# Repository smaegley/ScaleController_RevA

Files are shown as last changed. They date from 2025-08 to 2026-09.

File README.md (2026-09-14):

Scale Controller Rev-A

A custom ESP32-based scale controller PCB derived from the KLP-5e ESP32 Sensor Board. This design integrates an HX711 24-bit ADC and supports 4× half-bridge load cells, with output to a 1.3” SSD1306 OLED display over I²C. The board is designed to run ESPHome, making it easy to integrate into Home Assistant or other IoT ecosystems.

⸻

✨ Features
	•	ESP32-C3-WROOM-02-H4 module (RISC-V, Wi-Fi + BLE)
	•	USB-C connector for power and flashing (via on-board CP2102N USB-UART bridge, with USBLC6 ESD protection)
	•	Onboard LM1117 LDO regulator (5V → 3.3V)
	•	HX711 24-bit ADC for load cell integration
	•	4× JST-PH-3 connectors for half-bridge load cells
	•	1× JST-PH-4 header for I²C OLED (SSD1306 128×64, 1.3”)
	•	Tare via the on-board BOOT button (SW1, GPIO9) — no extra hardware needed
	•	J6 expansion header (5-pin): 3V3, GPIO8, GPIO18, GPIO19, GND

Verified pin map (from the KiCad netlist):

| Function | ESP32-C3 GPIO | Notes |
|---|---|---|
| HX711 DOUT | GPIO6 | |
| HX711 PD_SCK | GPIO5 | |
| I²C SDA (OLED)  | GPIO4 | |
| I²C SCL (OLED)  | GPIO3 | |
| Tare button | GPIO9 | reuses BOOT button SW1 (on board) |

Rev-A has no dedicated user I/O beyond the BOOT-button tare; status is shown on
the OLED and in Home Assistant. A physical status LED (GPIO19) is deferred to Rev-B.

⸻

🛠️ Getting Started

Hardware Bring-Up Checklist
	1.	Power via USB-C → check +3.3V rail is stable.
	2.	I²C scan → OLED should respond at 0x3C.
	3.	HX711 baseline → confirm stable raw counts with no load.
	4.	Add load cells one by one → verify diagonal pairs add/subtract as expected.
	5.	Tare with empty platform.
	6.	Calibrate using a known mass (e.g. 1000 g). Compute calibration factor.

ESPHome Config

The full, ready-to-build configuration lives in firmware/scale-controller.yaml
(targets the ESP32-C3 with the verified pin map above). To use it:

	1.	Install ESPHome (pip install esphome or the Home Assistant add-on).
	2.	cp firmware/secrets.yaml.example firmware/secrets.yaml and fill in your Wi-Fi/API/OTA values.
	3.	esphome run firmware/scale-controller.yaml (first flash over USB-C, then OTA).

Key pins (see firmware/scale-controller.yaml for the complete config):

i2c:
  sda: GPIO4
  scl: GPIO3

sensor:
  - platform: hx711
    id: hx711_raw
    dout_pin: GPIO6
    clk_pin: GPIO5
    gain: 128

⸻

📂 Repo Structure
	•	KiCad project/ScaleController_RevA.kicad_pro — main KiCad project
	•	KiCad project/*.kicad_sch — schematics (root + ESP32-C3, HX711 load-cell summing, OLED header; user_interface is nested under the ESP32-C3 sheet)
	•	KiCad project/ScaleController_RevA.kicad_pcb — PCB layout (footprints placed; routing not yet started)
	•	firmware/scale-controller.yaml — ESPHome configuration
	•	fabrication/ — Gerbers, BOM, pick-and-place (generated; gitignored)
	•	docs/ — bring-up notes, calibration steps

⸻

⚖️ License & Attribution

This project is licensed under the CERN Open Hardware Licence Version 2 – Strongly Reciprocal (CERN-OHL-S v2).

Derived from futureshocked/KLP-5e-ESP32-sensor-board.
Copyright © 2025 Steve Maegley
Copyright © 2022–2023 futureshocked

You are free to use, modify, manufacture, and distribute this design, provided that you release your modifications under the same license.

⸻

🚀 Next Steps
	•	Schematic is complete for Rev-A (tare = BOOT button GPIO9; status LED deferred to Rev-B)
	•	Route the PCB (keep HX711 analog away from the antenna + regulator)
	•	Run DRC and fix violations
	•	Generate fabrication files (Gerbers, BOM, pick-and-place)
	•	Build Rev-A prototype and validate
	•	Document calibration workflow with photos

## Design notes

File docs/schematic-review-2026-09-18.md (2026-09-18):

# Schematic review — Scale Controller Rev-A, 18 September 2026

Method: every pin of every part checked from the exported netlist (`kicad-cli sch export
netlist`, commit 83b06ee) against the part datasheets — ESP32-C3-WROOM-02 v1.4,
CP2102N rev 1.5, HX711, LM1117, USBLC6-2SC6. Not a visual review; wiring only.

## Verdict

The board will power up, boot from flash and run. Two real design errors were found, both
in the programming path, plus a handful of robustness items. None require holding the
PCB order if the Rev-A workarounds below are acceptable.

## Findings

### F1 — Auto-program circuit is driven from a CTS input; the CP2102N QFN20 has no DTR  (design error)

`U4` is the **QFN20** CP2102N. Its pin 15 is **CTS (input)** and pin 16 is RTS; the QFN20
package has no DTR/DSR/DCD/RI (datasheet §5.3, Table 5.3). The classic ESP auto-reset
circuit (Q2/Q3, R33/R34) needs DTR *and* RTS as host-driven outputs. Here the net named
"DTS" is wired to CTS, which the host cannot drive.

Consequences, in order of importance:

1. **A host that asserts RTS holds the ESP32 in reset.** CTS floats high (CP2102N inputs
   default to weak pull-up, §4.3.1), so Q2's base is high; when the host asserts RTS the pin
   goes low, Q2 conducts and pulls EN low. Generic terminals (`screen`, `minicom`, pyserial
   defaults on Linux) assert RTS on open, so the board appears dead while the monitor is
   open. `esptool` and `esphome logs` de-assert RTS after opening, so those work.
2. **Automatic entry into download mode cannot work.** Q3 needs its emitter (DTS) driven
   low; nothing ever does. Flashing requires holding **BOOT (SW1)** while the tool resets
   the chip (esptool's RTS toggle still resets it, so hold BOOT, start esptool, release).

Rev-A: **do not populate Q2, Q3, R33, R34.** Program with BOOT + EN; use ESPHome OTA after
the first flash. This also removes consequence 1.
Rev-B: drop the CP2102N entirely and use the C3's native USB-Serial/JTAG on GPIO18/19
(already on J6), keeping U5 for ESD — or move to the QFN24/QFN28 CP2102N which has DTR.
Either way, rename the net.

### F2 — GPIO8 floats; it must be high to enter download boot  (design error)

ESP32-C3 Table 4: GPIO8 default **floating** (no internal pull). Table 6: Joint Download
Boot requires GPIO2 = 1, **GPIO8 = 1**, GPIO9 = 0. On this board GPIO8 goes only to J6
pin 2. With it floating, download mode is undefined — flashing may fail or be intermittent.

Rev-A: 10 kΩ between **J6 pin 1 (3.3 V) and J6 pin 2 (GPIO8)** — a resistor across two
adjacent header pins, no board rework. Rev-B: add the pull-up on the board.

### F3 — GPIO2 floats; datasheet recommends a pull-up  (robustness)

Table 6 note 2: "GPIO2 does not determine the boot mode, but it is recommended to pull this
pin up due to glitches." Module pin 16 is unconnected. Most boards run fine without it.
Rev-A: accept, or solder 10 kΩ from pad 16 to 3.3 V if boot proves flaky. Rev-B: add it.

### F4 — No I2C pull-ups on SDA/SCL  (robustness)

`/SDA` and `/SCL` contain only U3 and J9. The bus relies on the OLED module's on-board
pull-ups (most SSD1306 modules carry 4.7–10 kΩ; confirm on the Hosyond board) or the
C3's ~45 kΩ internal pull-ups. Rev-B: 4.7 kΩ pair on the board so J9 works with any module.

### F5 — BOOT (GPIO9) has no external pull-up  (robustness)

Relies on the C3's internal weak pull-up (~45 kΩ, Table 4 says default 1). With C21
(0.1 µF) that is a 4.5 ms rise, versus the 10 ms EN delay from R32/C22 — OK, but 10 kΩ to
3.3 V is the Espressif reference and makes the latch timing comfortable. Rev-B.

### F6 — HX711 input filter corner is very high  (optional)

R15/R16 100 Ω with C12/C13 4.7 nF gives f_c ≈ 340 kHz — nearly no filtering of the bridge
signal. Harmless (many HX711 boards have none). Rev-B option: 1 kΩ + 10 nF C0G ≈ 16 kHz.
Keep the parts matched between channels.

### F7 — HX711 AGND pin is on GND, everything else analogue is on AGND  (note)

U6 pin 5 → GND directly; C12–C17, VFB, INB±, RATE → AGND, tied to GND at NT1. Electrically
identical; only the physical tie point matters. Layout was done with this in mind (17 Sept
note). No action.

### F8 — TX/RX LEDs need one-time CP2102N configuration  (note)

D5/D6 hang off GPIO.2/GPIO.3. Datasheet §4.3.1: GPIO pins default to GPIO input
(open-drain, weak pull-up), so the LEDs stay off until TXT/RXT alternate functions are
enabled with Simplicity Studio's Xpress Configurator over USB. Not a fault.

## Verified correct

- **USB-C**: VBUS A4/A9/B4/B9 → /VBUS; D+/D− both rows paired; CC1/CC2 each 5.1 kΩ to GND
  (Rd, sink); SBU NC; shield and GND to GND.
- **ESD**: USBLC6-2SC6 pins 1/6 and 3/4 are the same internal line; connector side on
  6/4, chip side on 1/3; VBUS on 5, GND on 2.
- **Power path**: VBUS → F1 (1.1 A PPTC) → FB1 → +5V → U2 VIN. LM1117 SOT-223 pinout
  (1 GND, 2/4 VOUT, 3 VIN) correct. 10 µF tantalum in, 3 × 10 µF tantalum + ceramics out —
  meets the ESR requirement. Dissipation ≈ 0.25 W average, 0.6 W at Wi-Fi TX peaks: fine
  with the pour.
- **CP2102N**: regulator-bypassed mode (VDD = VREGIN = 3.3 V, datasheet Fig. 2.3);
  RSTb 1 kΩ pull-up (Fig. 2.1 recommends exactly 1 kΩ); VBUS sense divider 22.1 k / 47.5 k
  matches Fig. 2.6; 1 µF on the VBUS pin. UART correctly crossed: U4 TXD → U3 RXD, U4 RXD
  ← U3 TXD.
- **ESP32-C3 module**: pin map matches the WROOM-02 table; EN has 10 kΩ + 1 µF + button;
  3V3 and all 21 GND pins connected. IO3/IO4 (I2C), IO5/IO6 (HX711), IO18/19/8 to J6.
- **HX711 external-supply configuration**: VSUP = AVDD = DVDD = 3.3 V, VFB → AGND, BASE NC
  (regulator disabled, per datasheet application circuit); VBG 0.1 µF; RATE low = 10 SPS;
  XI grounded = internal oscillator; channel B inputs tied to AGND. Bridge excitation E+/E−
  is the same 3.3 V rail as AVDD, so the measurement is ratiometric.
- **Load-cell wiring**: J3/J7 feed S+, J5/J8 feed S−, and the S− pair has E+/E− swapped on
  the board, so all four half-bridge cells plug in identically (white/red/black) and every
  corner produces a same-sign output. This is the standard 4-cell parallel Wheatstone.
  For the most even corner response, mount the S+ pair (LC1/LC3 = J3/J7) diagonally.
- **Firmware pins** (`firmware/scale-controller.yaml`) match the netlist: DOUT GPIO6,
  PD_SCK GPIO5, SDA GPIO4, SCL GPIO3, tare on GPIO9.
- **OLED J9**: GND, 3V3, SCL, SDA — matches the module's pin order.
- No unintended shorts: every named net has the expected members; only intended pins are
  unconnected (IO0/1/2/7/10, SBU1/2, CP2102N GPIO/suspend/wakeup, HX711 BASE/XO).

## Recommended actions

| when | action |
|---|---|
| Rev-A order | Order as is. Mark **Q2, Q3, R33, R34 DNP** on the assembly BOM (or don't fit them). |
| Rev-A bring-up | 10 kΩ across J6 pins 1–2 (GPIO8 pull-up). Flash with BOOT held; OTA afterwards. |
| Rev-B | Native USB (GPIO18/19) instead of CP2102N; pull-ups on GPIO2, GPIO8, GPIO9; 4.7 kΩ I2C pull-ups; optional 1 kΩ/10 nF HX711 filter; status LED on a free GPIO. |

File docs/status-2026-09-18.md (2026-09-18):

# Scale Controller Rev-A — Status, 18 September 2026

Supersedes `status-2026-09-17.md`. Pre-order checklist complete, schematic review done and
its findings **designed out** (see below); fab package regenerated from the reworked board.
DRC 0 errors / 0 unconnected, ERC 0 symbol mismatches, schematic↔board parity clean.

## Design rework after the schematic review (evening)

`docs/schematic-review-2026-09-18.md` found that the QFN20 CP2102N has no DTR, so the
DTR/RTS auto-program circuit could never work, and that GPIO8 floated (needed high for
download boot). Rather than work around it, the USB path was redesigned:

- **CP2102N and its 13 support parts removed** (U4, R11–R13, C9–C11, D6, R18, Q2, Q3,
  R33, R34). USB D+/D− now run from the ESD diode U5 to the module's native
  USB-Serial/JTAG pins (IO19 = D+, IO18 = D−). esptool/ESPHome reset and enter download
  mode over USB by themselves; no buttons needed for flashing. UART0 is broken out on J6.
- **Pull-ups added**: R3 10 k GPIO8, R4 10 k GPIO2, R5 10 k GPIO9/BOOT, R6/R7 4.7 k SDA/SCL.
- **Status LED**: D5 (green) + R14 330 R kept and re-homed to **GPIO7** (active-low), placed
  between the module and the HX711 with a STATUS silk label. ESPHome `status_led` drives it.
- **J6 re-pinned**: 1 = 3.3 V, 2 = GPIO10, 3 = U0TXD (GPIO21), 4 = U0RXD (GPIO20), 5 = GND.
- Board: the five long back-side bus lines between the module and J6 were kept and
  re-terminated (USB pair on the top two, UART on the next two, GPIO10 on the fifth,
  extended to pad 10). GPIO8 and STATUS_LED run down the free channel between the PD_SCK
  and SDA diagonals. I2C/IO2 pull-ups sit in the right-edge strip. 44 parts, 23 BOM lines.
- Firmware: `logger: hardware_uart: USB_SERIAL_JTAG`, `status_led` on GPIO7, pin map updated.

## Done today

- **Design rules**: deleted the global `annular_width` ignore from `.kicad_dru` (nothing
  needs it since the DFM pass). Restored `min_copper_edge_clearance` to **0.3 mm** — the DFM
  commit set it, but the GUI zone-refill save that followed wrote the old project file back
  over it (0.2). Board meets 0.3 either way.
- **Stackup**: PCBWay standard 4-layer 1.6 mm — 7628 prepreg 0.19 mm ×2, core 1.03 mm,
  1 oz on all four layers. Gerber job file now carries it.
- **Symbol libraries**: `LM1117MPX-3.3_NOPB`, `ESP32-C3-WROOM-02-H4` and `MTMM-103-03-T-S-150`
  rewritten in KiCad 9 format from the schematic copies. The MTMM copy has pins 1/2/3 (JST PH
  pads); the old library still had 01/02/03, so "update from library" would have unwired the
  sockets. SnapEDA `Description_1` junk fields removed everywhere.
- **BOM fixes**: J3/J5/J7/J8 → JST **B3B-PH-K-S** (symbol name unchanged); J1 → HRO
  **TYPE-C-31-M-12**; C9 value 4.7u → 10u to match its KEMET T491A 10 µF part number
  (LM1117 output cap); capacitor values normalised to `0.1u / 1u / 10u` so identical 0805
  parts group (30 → 27 BOM lines). Legacy KLP-5e `BOM.ods` deleted.
- **DRC exclusions**: the 4 silk-over-edge warnings (J1 face, U3 antenna notch) excluded in
  the GUI. Remaining warning: U3 footprint differs from library — intentional.
- **Fab package** in `fabrication/RevA-2026-09-18/` (git-ignored, regenerate as below):
  schematic PDF (6 pages), `-BOM.csv` (all fields), `-BOM-PCBWay.csv` (coalesced
  manufacturer/MPN), Gerbers + Excellon drill (Protel ext., separate PTH/NPTH, drill maps),
  `-gerbers.zip`, `-pos-top.csv` (43 parts), `-pos-bottom.csv` (J9 only).
- **Order notes**: `docs/pcbway-order-notes.md`.
- **Package as sent**: built from commit 271f942 (final refill); `ScaleController_RevA-gerbers.zip`
  14 files, sha256 starts `dd51ac8b2ae7093b`. Regenerating from that commit reproduces it.

## Regenerating the outputs

```
cd "KiCad project"
kicad-cli sch export pdf -o ../fabrication/RevA-<date>/ScaleController_RevA-schematic.pdf ScaleController_RevA.kicad_sch
kicad-cli sch export bom -o ../fabrication/RevA-<date>/ScaleController_RevA-BOM.csv \
  --fields 'Reference,${QUANTITY},Value,Footprint,MF,Manufacturer_Name,MANUFACTURER,MP,Manufacturer_Part_Number,Mouser Part Number,Description,Datasheet,${DNP}' \
  --group-by 'Value,Footprint,MP,Manufacturer_Part_Number' --ref-range-delimiter '' ScaleController_RevA.kicad_sch
kicad-cli pcb export gerbers -o ../fabrication/RevA-<date>/gerbers/ \
  -l F.Cu,In1.Cu,In2.Cu,B.Cu,F.Paste,B.Paste,F.SilkS,B.SilkS,F.Mask,B.Mask,Edge.Cuts --subtract-soldermask ScaleController_RevA.kicad_pcb
kicad-cli pcb export drill -o ../fabrication/RevA-<date>/gerbers/ --excellon-separate-th --excellon-units mm --generate-map ScaleController_RevA.kicad_pcb
kicad-cli pcb export pos -o ../fabrication/RevA-<date>/ScaleController_RevA-pos-top.csv --side front --format csv --units mm --exclude-dnp ScaleController_RevA.kicad_pcb
kicad-cli pcb export pos -o ../fabrication/RevA-<date>/ScaleController_RevA-pos-bottom.csv --side back --format csv --units mm --exclude-dnp ScaleController_RevA.kicad_pcb
```

## PCBWay order (placed 18 Sept, under review)

| item | product no. | qty | quoted |
|---|---|---|---|
| PCB, 4-layer 90 × 52.9 mm 1.6 mm, green/white, HASL-LF, 6/6 mil, 0.3 mm | W1153444AS5P3 | 5 | $32.66, 4–5 days |
| Assembly, turnkey, top side, 22 unique / 38 SMD / 5 THT, J9 not fitted | T-5P4W1153444A | 5 | $29.00 + components (quoted after review) |

Files uploaded: gerbers.zip, BOM-PCBWay.csv, pos-top.csv, assembly-top.pdf. Sales rep: Chloe.

## Next

1. Upload `ScaleController_RevA-gerbers.zip` to PCBWay with the notes in
   `docs/pcbway-order-notes.md`; pick surface finish (no fine-pitch QFN any more, so
   lead-free HASL is fine; ENIG still nicer for the 0.5 mm-pitch module pads).
2. If quoting assembly: `-BOM-PCBWay.csv` + `-pos-top.csv`. 11 of 23 lines are generic
   (0805 R/C, header/socket) — fill in exact MPNs/LCSC numbers if that matters. C12/C13/C16
   dielectrics and the HX711 source are specified in the BOM; check the quote honours them.
3. Enclosure: the J9 display mount is prototype-only. Decide between a different mount
   and integrating the display on the board for Rev-B (see 17 Sept note for standoffs,
   hole positions, and USB/antenna overhangs).
4. Bring-up per `TODO.md` once boards arrive.

## Working notes

- Headless copper edits: never use a generic "dangling end" sweep over live areas — a track
  ending on the *middle* of another track (T-junction) looks dangling to a naive endpoint
  test. Delete by explicit coordinates and let DRC's `track_dangling`/`via_dangling` list
  guide the next pass.
- Headless edits to `.kicad_pro` are lost if any KiCad editor is open, even without a
  visible lock — the GUI writes the project file back on save/close. Edit it only when
  the whole project is closed, then check `git diff` after Steve's next GUI save.
- `kicad-cli` on VM 201 has no global symbol/footprint libraries, so ERC shows 85
  `lib_symbol_issues` and DRC shows `lib_footprint_issues` when run outside the project
  dir. Both are environment noise; run from `KiCad project/` for a faithful DRC.

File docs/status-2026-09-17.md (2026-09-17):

# Scale Controller Rev-A — Status, 17 September 2026

Supersedes `status-2026-09-15.md`. Board fully routed, DRC 0 errors / 0 unrouted,
5 benign warnings, everything pushed (`origin/main` = c55ba90).

## Changes since 15 Sept

- **Load-cell sockets** → JST PH B3B-PH-K (2.0 mm, friction lock). One connector pair
  is inverted on the board (J3/J7 vs J5/J8) so all four half-bridge cells plug in
  identically: pin 1 white, pin 2 red (centre tap), pin 3 black. Legend on silk.
  Rows at 5.7 mm pitch; NT2/NT3 moved above the column.
- **USB-C** → HRO TYPE-C-31-M-12 (SMD signal pins, four PTH shell legs), replacing the
  Bel hybrid whose staggered PTH row failed PCBWay's hole-spacing and ring limits.
  Added R1/R2 5.1 kΩ CC pull-downs (board now powers from C-to-C cables and chargers).
  Rendered with the GCT USB4105 3D model as stand-in (KiCad ships no HRO model).
- **Display header J9** moved to the **back side**, pin order **GND, 3V3, SCL, SDA**
  to match the Hosyond 0.96" I2C module. The module plugs in from below and lies
  flat under the board, clear of the load-cell sockets. DISP1 is a pad-less
  placeholder footprint + model for fit checks only (nominal 27 × 27.5 mm).
- **DFM for PCBWay**: all vias 0.6/0.3 mm (0.15 mm ring; one 0.55/0.3 at U4 pad 8),
  ESP32 module ground-grid pads 0.6 mm, copper-to-edge rule 0.3 mm, net-class vias
  0.6/0.3, U4 pin 12 grounded into the centre pad (via in pad).
- Silkscreen labels; standard-library footprints refreshed; E+/E− naming tidied.

## Before ordering (in order)

1. `.kicad_dru`: replace the global `annular_width` ignore with one scoped to U3's
   ground grid.
2. Board stackup → PCBWay standard 4-layer 1.6 mm (7628 prepreg ≈0.19 mm after
   lamination, 1.03 mm core, 1 oz all layers).
3. Outputs: schematic PDF, BOM from schematic (delete the KLP-5e `BOM.ods`),
   Gerbers + drill (Protel extensions), pick-and-place (top side; J9 and the JST
   sockets are THT).
4. PCBWay order notes: one 0.55 mm via (U4-VBUS, ring 0.125 mm); J1 footprint
   peg-to-shell-leg hole spacing 0.35 mm is the manufacturer's geometry; J9 is a
   bottom-side THT part (hand-solder if not assembling THT).

## Enclosure notes

- Standoffs ≥ 14 mm under the board for the display module.
- Buttons and USB face up; display faces down through J9 → decide board orientation.
- USB-C face protrudes ~1.2 mm past the board edge; ESP32 antenna overhangs the top edge.
- Four M3 mounting holes: (116, 76.5) (116.5, 119.5) (197, 120.5) (169, 84) mm in
  board coordinates; board 89.9 × 52.8 mm with the antenna notch top right.

## Working notes

- Headless edits (`scratchpad/pcbtool.py` + per-task design scripts) are verified with
  `kicad-cli pcb drc` on a fill-stripped copy, then written only while the PCB editor
  is closed; Steve refills in the GUI afterwards.
- KiCad symbol pin numbers must match footprint pad names ("1" vs "01"), or Update PCB
  silently drops the pad nets. Check netlist *membership* after any connector swap.

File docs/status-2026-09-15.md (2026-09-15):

# Scale Controller Rev-A — Status, 15 September 2026

## Where things stand

**The board is fully routed and passes DRC.** 0 unrouted connections, 0 errors,
4 warnings (all intentional or cosmetic, see below). Everything is committed and
pushed; `origin/main` is current.

| Item | State |
|---|---|
| Schematic | Complete for Rev-A. ERC 0 errors. |
| Placement | Done. 4× M3 mounting holes added (H1–H4). |
| Routing | 141/141 connections. 350 track segments, 66 vias, 4-layer (F.Cu / In1 GND plane / In2 3.3V plane / B.Cu). |
| DRC | 0 errors. Warnings: J1 + U3 differ from library copies (deliberate), 2× module silk outline over the antenna edge. |
| Footprints | Standard parts refreshed from KiCad 9 libraries; J1 and U3 kept on their modified copies. |

## What was fixed along the way (14–15 Sept)

Bugs found in the inherited design, all corrected in the schematic and reflected on the board:

- **Three separate 3.3V nets** (`3.3V`, `+3.3V`, `+3V3`) left the HX711 and the OLED
  unpowered. Unified onto one net.
- **HX711 input filters were wired in series** (S± → 100R → 4.7 nF → INA±), which
  blocks the DC bridge signal. Rewired as shunt caps to AGND.
- Stale KLP-5e leftovers removed: test points TP2/TP4, 104 silkscreen items,
  eight top-layer copper islands, duplicate ground zones, In2 power islands.
- Net classes: two classes had zero-annular-ring vias; `+5V` was in no class.
- Board had no mounting holes.

Layout decisions worth knowing:

- Load-cell connectors were re-ordered so the two S+ cells are adjacent
  (J3, J7) and the two S− cells adjacent (J5, J8). Wire the cells accordingly.
- HX711 cap/resistor column re-ordered pin by pin; NT2/NT3 net ties moved beside
  the connectors. AGND meets GND only at NT1.
- A five-lane bottom-layer bus runs along the top edge (between the antenna
  keepout and mounting hole H4) carrying the UART pair and GPIO8/18/19.
- USB D± use short bottom-layer hops around the connector's mirrored pin rows.
- J1 (USB-C) has a custom DRC rule allowing 0.127 mm between its own pads and a
  solid connection to the ground plane; J1 and U3 allow bridged mask apertures.

## Before ordering boards

1. **Silkscreen labels** — all board-level silk was purged. Needed: connector
   names and load-cell assignment (S+ → J3/J7, S− → J5/J8), BOOT/EN buttons,
   J6 pin names (3V3, GPIO8, GPIO18, GPIO19, GND), OLED header pins, board
   name and revision.
2. **Fab capability check** — J1's through-hole row has 0.35 mm hole-to-hole
   spacing; JLCPCB lists 0.5 mm. This footprint was built in the KLP-5e
   prototypes, but confirm with the chosen fab. Also confirm the 4-layer
   stackup (file has 0.1 mm prepregs; fabs will substitute their standard).
3. **Design rules** — `ScaleController_RevA.kicad_dru` has a global rule that
   silences the annular-ring check; narrow it to the ESP32 module's ground grid.
4. **Outputs** — schematic PDF, BOM with LCSC numbers, Gerbers + drill,
   pick-and-place. Then a quote.

## Working notes

- Mac ↔ VM: the repo is edited from the Mac over `smb://10.0.1.121/projects`.
  `.git` is hidden from the share (Samba veto) and KiCad's git integration is
  disabled on the Mac; both were needed after a git index got wiped on 14 Sept.
- Workflow that worked: Steve routes in the GUI in small chunks, Claude verifies
  each save with `kicad-cli` DRC. Dense sections (analog, the long digital runs)
  were designed headlessly on a scratch copy, DRC-verified, and written to the
  board with the PCB editor closed.
- KiCad 9.0.9 on both sides. Do not move to KiCad 10 during Rev-A.

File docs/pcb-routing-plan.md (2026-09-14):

# ScaleController Rev-A — PCB Routing & Layout Plan

Status as of 2026-07-05: **55 footprints placed, 0 tracks routed.** Board is
~90 × 53 mm, 4-layer. This document is the routing strategy — the actual work
happens in the KiCad PCB editor. It is grounded in the current placement and
the verified netlist (68 nets), not generic advice.

The single most important idea for this board: **it is a mixed-signal design.**
The HX711 measures the load cell bridge at the **microvolt** level, sitting a
few cm from a 2.4 GHz Wi-Fi radio and a switching USB bridge. Most of the plan
below exists to keep that tiny analog signal clean.

---

## 1. Layer stackup (4-layer)

Current layers: `F.Cu` (signal), `In1.Cu` (power), `In2.Cu` (power), `B.Cu` (signal).

**Recommended assignment:**

| Layer | Use |
|---|---|
| F.Cu | Primary signal routing + component side |
| In1.Cu  | **Solid, unbroken GND plane** (layer type stays "power plane"; KiCad has no separate ground type) |
| In2.Cu  | Power pours: +3.3V (main), with +5V/VBUS islands as needed |
| B.Cu | Secondary signal routing + GND fill |

Why: a continuous ground plane directly under the signal layers gives every
trace a clean, low-impedance return path — this is the biggest single lever for
both analog noise and Wi-Fi/USB EMI. **Do not split or slot In1.Cu**, especially
not under the HX711, the ESP32, or the USB pair. (See §5 for how analog ground
is handled *without* cutting the plane.)

Set the board thickness/stackup so the F.Cu↔In1.Cu spacing is small (thin
prepreg) — it tightens return-path coupling and helps controlled impedance for
the USB pair.

---

## 2. Placement zones (already mostly good)

From current coordinates (mm), the board self-organizes into two zones:

```
     LEFT / CENTER  (power + digital + USB)        RIGHT (analog + RF)
   ┌───────────────────────────────────┬──────────────────────────────┐
   │ J6 expansion (far left)            │              U3 ESP32-C3 (top)│  <- antenna to top edge
   │ U2 LM1117 LDO   D4/5/6 LEDs        │                               │
   │ U4 CP2102N   U5 USBLC6             │   J3 ┐                        │
   │ F1 fuse  FB1 ferrite               │   J5 ├ load cells   U6 HX711  │
   │ SW1 BOOT  SW2 EN                   │   J7 │             C12-C17 dcpl│
   │ J1 USB-C (bottom edge)             │   J8 ┘                        │
   └───────────────────────────────────┴──────────────────────────────┘
```

**Keep this separation.** The mixed-signal boundary runs roughly vertically
through the middle. Route so that digital/USB/switching currents stay left, and
analog stays right.

Placement tweaks to check before routing:
- **U6 (HX711) decoupling caps** C12–C17 are in a column at x≈181.8 — good, keep
  each cap's ground via right at the pad.
- **Load-cell connectors J3/J5/J7/J8** feed `E+/E-` and `S_PLUS_GRP/S_MINUS_GRP`
  into the summing network → HX711 INA±. Keep them close and grouped (they are).
- Confirm **U3's PCB antenna overhangs the top board edge** (U3 is at y≈82.8,
  top edge y≈72.2). See §6.

---

## 3. Net classes (already defined — good)

The project already has sensible classes. Confirm these before routing:

| Class | Track  | Clearance | Notes |
|---|---|---|---|
| GND | 0.50mm | 0.20mm | plus plane |
| 3.3V | 0.50mm | 0.20mm | wide for current + low drop |
| VBUS | 0.60mm | 0.15mm | USB power in |
| 5V_USB | 0.25mm | 0.20mm | consider widening to ~0.4mm |
| USB_data | 0.20mm | 0.15mm | **differential pair — see §7** |
| I2C | 0.30mm | 0.15mm | SDA/SCL to OLED header |
| SPI | 0.30mm | 0.15mm | HX711 DOUT/PD_SCK live here |
| sensor_data  | 0.25mm | 0.15mm | assign the analog A+/A- nets here (§4)  |
| GPIO/control | 0.25mm | 0.15mm | general I/O |

**Action:** assign the analog bridge nets `A+`, `A-`, `E+`, `E-`,
`S_PLUS_GRP`, `S_MINUS_GRP`, `AGND` to a dedicated class (e.g. `sensor_data`)
so they're easy to see and rule-check.

---

## 4. Analog front end — the critical part

The sensitive nets (from the netlist):
- `A+` / `A-`  → HX711 INA+ (pin 8) / INA- (pin 7): the differential measurement input.
- `E+` / `E-`  → load-cell excitation (bridge drive).
- `S_PLUS_GRP` / `S_MINUS_GRP` → connector signal lines into the summing network.
- `AGND` → analog ground / reference (VFB, RATE, INB± tie here).
- `Net-(U6-VBG)` → bandgap reference bypass.

Rules:
1. **Route `A+`/`A-` as a tight differential pair**, matched length, as **short
   as possible**, entirely within the analog zone. Never run them near the
   antenna, the USB pair, the LEDs, or the LDO.
2. **Keep `A+`/`A-` on one layer over the solid ground plane** — avoid vias on
   these nets if you can; each via is a small discontinuity and a coupling point.
3. **Guard the analog input**: flood the analog zone with GND copper on F.Cu and
   B.Cu, and stitch it to the In1 ground plane with vias around (not through) the
   `A+`/`A-` route. This forms a shield.
4. **`E+`/`E-`** carry more current (they drive the bridge) — a bit wider, still
   kept as a pair alongside the signal pair from the connectors.
5. Put the **HX711 AVDD/DVDD/VSUP decoupling caps** (C12–C17) hard against the
   pins with the shortest possible ground return.
6. Keep the **VBG bypass cap** right at pin 6.
7. Nothing switching (LED lines, USB, buck/LDO feedback, GPIO toggling) crosses
   the analog zone.

---

## 5. Grounding strategy (single-point analog/digital tie)

`AGND` (HX711 analog ground) and `GND` (system ground) are separate nets in the
schematic but must meet at **exactly one point**.

- Use the **solid In1 ground plane as the system ground.**
- Create the analog ground as a **local pour in the HX711 region** tied to the
  main plane at a **single stitching point** directly under the HX711's AGND
  pin (pin 5). In KiCad, place the AGND zone and connect it to GND with one via
  / one short bridge near U6 pin 5.
- **Do not** create a long slot in In1.Cu to "separate" grounds — a moat under
  the analog signals does more harm (broken return path) than good. Single-point
  tie + local pour is enough at HX711 speeds.

---

## 6. RF / antenna keepout (ESP32-C3 module, U3)

- The WROOM module's PCB antenna **must overhang the board edge** with a
  **copper keepout on ALL layers** (F.Cu, In1.Cu, In2.Cu, B.Cu) beneath and
  around it — no ground pour, no traces. Follow the ESP32-C3-WROOM-02 datasheet
  keep-out dimensions (in `KiCad project/Datasheets/`).
- Verify U3 is oriented so the antenna points off the top edge (y≈72), away from
  the HX711 and load-cell area.
- Ground-stitch vias in a "fence" around the module's ground pad and along the
  board edges near the antenna (but outside the keepout) to contain RF.
- Keep the HX711 and its analog traces on the opposite side of U3 from the
  antenna.

---

## 7. USB routing (J1 → U5 → U4)

- Route `USB_DP`/`USB_DN` (connector side) and `USB_D+`/`USB_D-` (bridge side) as
  a **90 Ω differential pair**, length-matched, short.
- **U5 (USBLC6 ESD array) goes right at the USB-C connector (J1)** so transients
  are clamped before reaching anything else. Signal flows J1 → U5 → U4.
- Keep the USB pair over solid ground; avoid vias/stubs. Don't route the pair
  near the analog zone or under the antenna.
- `VBUS` is wide (0.6mm class) — fuse F1 and ferrite FB1 are already in the power
  path; keep that inline.

---

## 8. Power routing

- `VBUS` (5V from USB-C) → F1 fuse → FB1 ferrite → `+5V` → U2 (LM1117) → `+3.3V`.
  Use the wide VBUS/3.3V classes; keep the LDO input/output caps close to U2.
- Flood `+3.3V` as a pour on In2.Cu; drop vias to each IC's supply pins.
- The LM1117 is a linear LDO — it dissipates (5-3.3)V × I as heat. Give U2 some
  copper area / a small pour on its tab net for heat spreading.
- Keep the LDO and its ripple **out of the analog zone** — feed the HX711's 3.3V
  from a quiet branch, ideally with a small series ferrite/RC into AVDD if noise
  shows up in bring-up.

---

## 9. Suggested routing order

1. **Board Setup**: set In1.Cu = ground, In2.Cu = power; confirm net classes (§3);
   assign analog nets to `sensor_data`.
2. Pour **In1 solid ground** plane.
3. Place/verify **antenna keepout** (§6).
4. Route the **USB differential pair** (§7) — constrained, do it early.
5. Route the **analog front end** `A+/A-`, `E+/E-`, `S±_GRP`, AGND pour (§4, §5).
6. Route **power**: VBUS/5V/3.3V, decoupling (§8).
7. Route the **digital** nets: SPI (HX711 DOUT/PD_SCK), I2C (OLED), GPIO, BOOT/EN.
8. Pour **F.Cu and B.Cu ground fills**; add **stitching vias** across the board
   and around the analog guard + antenna fence.
9. **Silkscreen**: label load-cell connectors (E+/E-/S) and corner placement,
   test points, tare(BOOT)/reset(EN) buttons.

---

## 10. Verification workflow (kicad-cli, headless-friendly)

After routing, from `KiCad project/`:

```bash
# Design Rule Check → report
kicad-cli pcb drc --severity-all --exit-code-violations \
  -o /tmp/drc.rpt ScaleController_RevA.kicad_pcb

# Board render for review (top + bottom)
kicad-cli pcb render --side top -o /tmp/pcb_top.png ScaleController_RevA.kicad_pcb
kicad-cli pcb render --side bottom -o /tmp/pcb_bottom.png ScaleController_RevA.kicad_pcb

# When ready to fabricate:
kicad-cli pcb export gerbers -o fabrication/ ScaleController_RevA.kicad_pcb
kicad-cli pcb export drill   -o fabrication/ ScaleController_RevA.kicad_pcb
kicad-cli sch export bom     -o fabrication/bom.csv ScaleController_RevA.kicad_sch
```

Target: **0 DRC errors** before generating fab files. `fabrication/` is
gitignored (regenerated output).

---

## 11. Open items to resolve before/while routing

- **Status LED**: deferred to Rev-B — no change needed for Rev-A routing.
- Confirm the **antenna keepout dimensions** against the ESP32-C3-WROOM-02 datasheet.
- Decide whether the HX711 3.3V needs a **dedicated filtered branch** (can be a
  bring-up-time decision; leave footprints for a series ferbead + cap near AVDD).

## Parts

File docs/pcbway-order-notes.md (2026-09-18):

# PCBWay order notes — Scale Controller Rev-A

Fab package: `fabrication/RevA-2026-09-18/ScaleController_RevA-gerbers.zip`
(regenerate with the kicad-cli commands in `docs/status-2026-09-18.md`).

## Board

| item | value |
|---|---|
| Size | 90.0 × 52.9 mm (outline incl. antenna notch, top right) |
| Layers | 4, KiCad order F.Cu / In1.Cu (GND) / In2.Cu (3.3 V) / B.Cu |
| Thickness | 1.6 mm, PCBWay standard 4-layer stackup: 7628 prepreg ≈0.19 mm, core 1.03 mm |
| Copper | 1 oz (35 µm) all four layers |
| Material | FR-4, TG ≥ 150 (PCBWay default is fine) |
| Surface finish | HASL lead-free or ENIG — choose at order time (ENIG recommended for the 0.5 mm QFN U4) |
| Mask / silk | green / white, or any standard colour; silkscreen on both sides |
| Min track / clearance | 0.20 mm track; net-class clearance 0.15 mm (Default), 3.3V/GND planes 0.2 mm |
| Vias | 0.60/0.30 mm (diameter/drill) throughout |
| PTH drills | 0.30, 0.60, 0.75, 1.00 mm |
| NPTH drills | 0.65, 3.20 mm (M3 mounting holes) |
| Copper to edge | 0.3 mm |
| Drill files | Excellon, mm, separate PTH / NPTH, absolute origin (same origin as Gerbers and pick-and-place) |
| Gerbers | RS-274X (X2 attributes), Protel extensions, solder mask subtracted from silkscreen |

## Notes to put in the "special requirements" box

1. All vias are 0.60/0.30 mm (0.15 mm annular ring).
2. **J1 (USB-C, HRO TYPE-C-31-M-12):** the spacing between the alignment-peg holes and the
   shell-leg holes is 0.35 mm. This is the connector manufacturer's footprint geometry;
   please do not flag or move these holes.
3. **J9 is a bottom-side through-hole part** (4-pin 2.54 mm socket for the OLED module).
   If ordering SMT assembly only, leave J9 unpopulated — it will be hand-soldered.
4. Silkscreen is intentionally drawn across the board edge at J1 and the U3 antenna
   notch; clip at the outline as usual.

## Assembly (if quoting SMT)

- Files: `ScaleController_RevA-BOM-PCBWay.csv` and `ScaleController_RevA-pos-top.csv`
  (`-pos-bottom.csv` lists only J9). Positions are in mm, KiCad absolute origin, Y axis up.
- 43 top-side parts, all SMD except the 4 JST PH sockets (J3/J5/J7/J8) and J6, which are
  through-hole on the top side. J9 (bottom) is the only bottom-side part.
- 12 of 23 BOM lines carry a manufacturer part number; the rest are generic 0805 R/C
  and the 2.54 mm header/socket. **Do not substitute** C12/C13 (C0G) or C16 (X7R ≥10 V);
  U6 must be a genuine or known-good Avia HX711 — dielectric and source are in the BOM Description.
- No USB-UART bridge on this revision: programming and logging use the ESP32-C3's native
  USB-Serial/JTAG through J1.
- U3 (ESP32-C3-WROOM-02-H4) is moisture-sensitive; standard MSL handling.

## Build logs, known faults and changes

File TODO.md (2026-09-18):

Scale Controller Rev-A — Project TODO

A running checklist of tasks for hardware, firmware, and documentation.
Updated 2026-09-18. See docs/status-2026-09-18.md for the current summary.

⸻

🖥️ KiCad / Hardware Design
	•	[x] Add HX711 child sheet (HX711_LoadCell_Summing.kicad_sch)
	•	[x] Wire 4× JST-PH-3 load cell connectors → HX711 (E+/E-, S± summing into INA±)
	•	[x] Add JST-PH-4 OLED header (SDA=GPIO4, SCL=GPIO3); 4.7k pull-ups R6/R7 on board (2026-09-18)
	•	[x] BOOT (SW1) + EN (SW2) buttons — tare reuses BOOT (GPIO9), no dedicated button needed
	•	[x] Run ERC — 0 errors (only benign lib-config warnings)
	•	[x] Status LED — D5 green on GPIO7 (active-low), added 2026-09-18 with the USB rework
	•	[x] Unified the three 3.3V power nets (2026-09-14). Root/C3/UI sheets use SparkFun-PowerSymbol:3.3V (net "3.3V"),
		HX711 sheet uses power:+3.3V (net "+3.3V", 7 pins incl. U6 VSUP/AVDD/DVDD), OLED sheet uses power:+3V3 (J9 pin 1).
		The three are separate nets — HX711 and OLED are unpowered. ERC is silent because power symbols self-drive.
		Change the 5 orphan symbols to SparkFun-PowerSymbol:3.3V, then Update PCB from Schematic (expect 138 unconnected).
	•	[x] PCB zones: deleted the 8 stale F.Cu micro-pours and 2 duplicate In1.Cu GND zones (2026-09-14)
	•	[ ] Pre-routing prep (found 2026-09-14 from render + file audit):
		[x] purged 104 board-level F.SilkS items inherited from KLP-5e (Charger, Sound sensor, MISO/MOSI, …); redo labels at silkscreen step
		[x] added 4× M3 mounting holes H1–H4 (board-only footprints)
		[x] moved FB1 from the bottom edge (133.7,123) to beside F1 (~133.0,107.3 rot 0) so VBUS→F1→FB1→U2 runs straight
		[x] net classes: Default and 5V_USB vias are 0.3/0.3 (zero annular ring) → 0.5/0.3; add "+5V" pattern to 5V_USB; widen 5V_USB track to 0.5 mm
		[x] deleted the In2.Cu VBUS and +5V_USB islands → solid 3.3V plane; route those nets on F.Cu
	•	[x] FIXED (7408cba): HX711 input filter was wired as a SERIES cap — S+ → R15 → C12 → INA+ (A+ net has only C12.2 + U6.8), same for R16/C13/INA-.
		A 4.7 nF in series blocks the DC bridge signal. Rewire so R15.1 goes straight to INA+ and C12 shunts that node to AGND (mirror for C13).
	•	[x] Deleted stale KLP-5e test points TP2 (on DOUT) and TP4 (on PD_SCK) from the schematic
	•	[x] Re-ordered the HX711 cap column (7f945fc); analog section routed so each cap sits beside its pin: C15/C14 by pins 1/3, C17 by pin 6, C13/C12 by pins 7/8, C16 last
	•	[x] Load-cell connectors → JST PH B3B-PH-K (friction lock) and on-board inversion of one cell pair (2026-09-17)
	•	[x] E+/E- naming tidied: E+ is the 3.3V-side excitation (NT2), E- the GND side (NT3)
	•	[x] Silkscreen: load-cell sockets labelled with wire-colour legend
	•	[x] DFM pass for PCBWay (2026-09-17): all vias 0.6/0.3 (0.15 ring), ESP32 module ground-grid pads 0.6, USB-C swapped to HRO TYPE-C-31-M-12 (SMD pins), CC1/CC2 5.1k pull-downs added, copper-to-edge rule 0.3
	•	[x] Order notes for PCBWay → docs/pcbway-order-notes.md (2026-09-18)
	•	[x] min_copper_edge_clearance restored to 0.3 (GUI save had reverted the DFM edit to 0.2) (2026-09-18)
	•	[x] BOM cleanup: C9 4.7u→10u (matches T491A 10 µF MPN), cap values normalised, J1 → HRO TYPE-C-31-M-12 (2026-09-18)
	•	[x] Resolved lib_symbol_mismatch warnings (2026-09-18): U2 LM1117, U3 ESP32-C3, J3/J5/J7/J8 MTMM-103-03 project libs rewritten from the
		schematic copies (KiCad 9 format; MTMM pins now 1/2/3 to match the JST PH pads); SnapEDA "Description_1" junk fields dropped. Netlist unchanged.
	•	[x] .kicad_dru: deleted the global annular_width ignore (2026-09-18) — U3 ground-grid pads are 0.6/0.3 since the DFM pass, DRC clean without it
	•	[x] Board stackup → PCBWay 4-layer 1.6 mm: 7628 prepreg 0.19 ×2, core 1.03, 1 oz all layers (2026-09-18)
	•	[x] J3/J5/J7/J8 Value/MF/MP → JST B3B-PH-K-S in schematic, project symbol lib and board footprints; stale SnapEDA fields dropped (2026-09-18).
		Symbol is still named MTMM-103-03-T-S-150 in the project lib (lib_id unchanged on purpose)
	•	[x] Route the PCB — all 141 connections routed 2026-09-14/15 (power, 3.3V, GND, analog, digital); 0 unrouted
	•	[x] Run DRC — 0 errors, 0 unrouted; footprints refreshed from KiCad 9 libs. 4 warnings left: J1/U3 lib mismatch (intentional: bridged mask + solid zone connect) and 2 U3-outline-vs-edge silk notes
	•	[x] Silkscreen: socket labels LC1-4 + wiring legend, button labels, J6/J9 pin names, LED names, board name/date (2026-09-17)

⸻

🔌 Fabrication
	•	[x] Schematic PDF — fabrication/RevA-2026-09-18/ (2026-09-18)
	•	[x] BOM CSV exported (all fields + PCBWay-style); [ ] add LCSC/JLC numbers if assembling there
	•	[x] Gerbers + drill (Protel ext., separate PTH/NPTH) + zip (2026-09-18)
	•	[x] Pick-and-place CSVs, top + bottom (2026-09-18)
	•	[ ] Upload to PCBWay for prototype quote
	•	[x] Netlist-level schematic review vs datasheets (2026-09-18) — docs/schematic-review-2026-09-18.md: 2 design errors in the programming path (F1 CP2102N QFN20 has no DTR; F2 GPIO8 floating), workarounds need no board change

⸻

⚙️ Firmware (ESPHome)
	•	[x] Create ESPHome YAML with verified pins — firmware/scale-controller.yaml (validated)
	•	[x] Tare action (physical BOOT button + Home Assistant button, persistent offset)
	•	[x] OLED UI (weight readout)
	•	[ ] Flash to a real prototype and confirm boot + Wi-Fi
	•	[ ] Calibrate with known weights; set calibration_factor
	•	[ ] Optional: auto-dim OLED, Wi-Fi status indicator, units toggle (g/oz)

⸻

🧪 Bring-Up & Testing
	•	[ ] Power test (USB-C, check 3.3 V rail)
	•	[ ] I²C scan → detect OLED at 0x3C
	•	[ ] HX711 baseline counts stable (no load)
	•	[ ] Add load cells one by one → confirm diagonal behavior
	•	[ ] Calibrate with 1000 g mass
	•	[ ] Corner test: ±200 g per corner, <1% error
	•	[ ] Wi-Fi test → confirm stable readings under RF load

⸻

📚 Documentation
	•	[x] PCB routing/layout plan — docs/pcb-routing-plan.md
	•	[x] README corrected for ESP32-C3 (module, LDO, USB bridge, verified pin map)
	•	[ ] Expand docs/bringup.md with photos/screenshots
	•	[ ] Add calibration instructions (step-by-step)
	•	[ ] Annotated PCB silkscreen screenshot
	•	[ ] Update README with assembly photo once built

⸻

🚀 Roadmap
	•	[ ] Rev-A prototype bring-up → fix issues
	•	[x] Review findings F1–F5 designed out in Rev-A (2026-09-18): native USB-Serial/JTAG replaces the CP2102N; 10k pull-ups on GPIO2/GPIO8/GPIO9; 4.7k I2C pull-ups; status LED D5 on GPIO7; J6 = 3.3V/GPIO10/U0TXD/U0RXD/GND
	•	[ ] Rev-B: optional 1k/10nF HX711 input filter (review F6)
	•	[ ] Prepare kit version: PCB + load cell mounts
	•	[ ] Write blog/guide on building an ESPHome Scale with this PCB

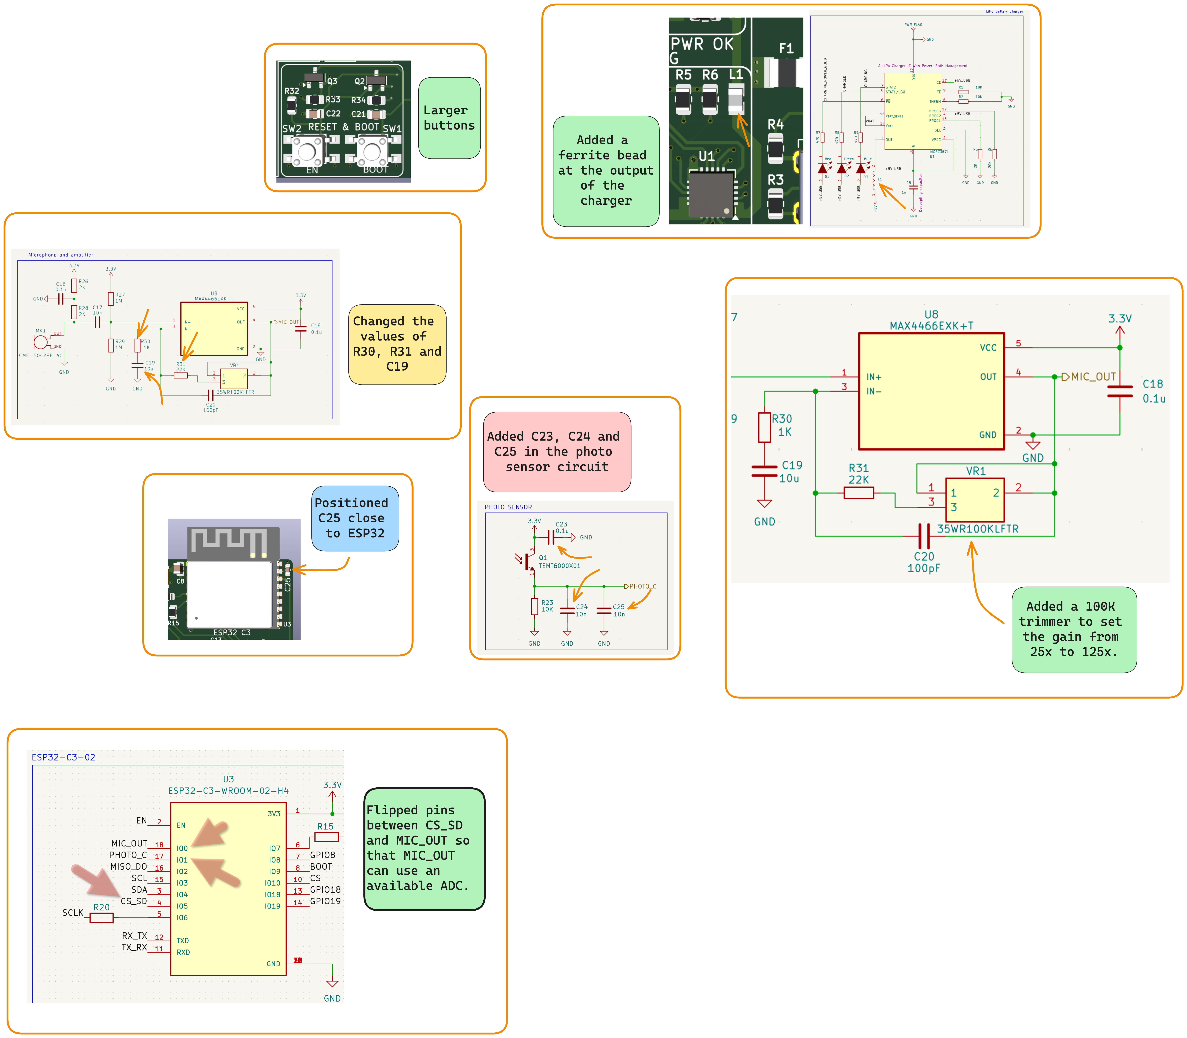
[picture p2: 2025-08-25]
ESP32 PCB prototype 2 improvements and fixes.png

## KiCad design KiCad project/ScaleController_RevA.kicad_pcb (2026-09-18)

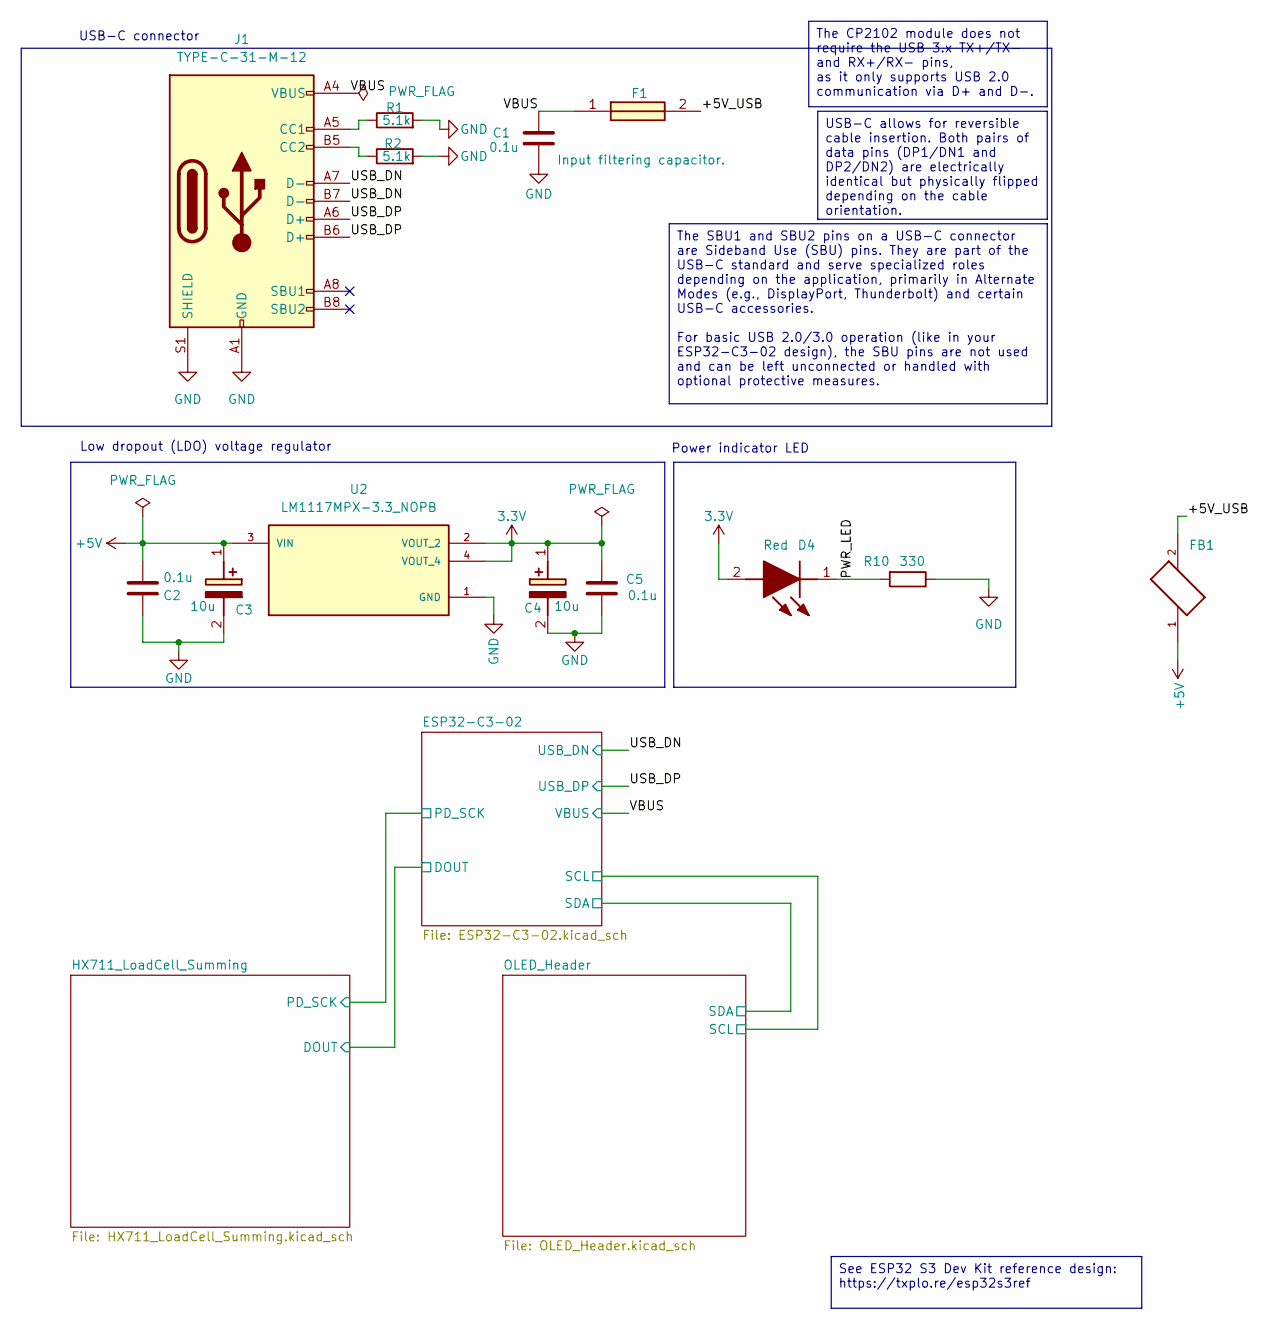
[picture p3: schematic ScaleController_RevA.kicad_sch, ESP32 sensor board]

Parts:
C1, C2, C5: 0.1u; C_0805_2012Metric; Voltage 1kV; Tolerance 100%
C3, C4: 10u; T491A; Voltage 1kV; Tolerance 100%; Manufacturer_Part_Number T491A106K010AT7280; Mouser Part Number 80-T491A106K107280
D4: Red; LEDC2012X120N; Manufacturer_Part_Number LTST-C170KRKT; Mouser Part Number 859-LTST-C170KRKT
F1: 0ZCH0110AF2E; FUSC3226X100N; Manufacturer_Part_Number 0ZCH0110AF2E
FB1: FBMJ2125HM330-T; BEADC2012X105N
J1: TYPE-C-31-M-12; USB_C_Receptacle_HRO_TYPE-C-31-M-12
R1, R2: 5.1k; R_0805_2012Metric
R10: 330; R_0805_2012Metric
U2: LM1117MPX-3.3_NOPB; VREG_LM1117MPX-3.3; Mouser Part Number 926-LM1117MPX3.3NOPB

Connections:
3.3V: C4.1 (+), C5.1, D4.2 (A), U2.2 (VOUT_2), U2.4 (VOUT_4); also elsewhere on the board
+5V: C2.1, C3.1 (+), FB1.1, U2.3 (VIN)
/+5V_USB: F1.2, FB1.2
/PWR_LED: D4.1 (K), R10.2
/USB_DN: J1.A7 (D-), J1.B7 (D-); also elsewhere on the board
/USB_DP: J1.A6 (D+), J1.B6 (D+); also elsewhere on the board
/VBUS: C1.1, F1.1, J1.A4 (VBUS), J1.A9 (VBUS), J1.B4 (VBUS), J1.B9 (VBUS); also elsewhere on the board
GND: C1.2, C2.2, C3.2 (-), C4.2 (-), C5.2, J1.A1 (GND), J1.A12 (GND), J1.B1 (GND), J1.B12 (GND), J1.S1 (SHIELD), R1.2, R2.2, R10.1, U2.1 (GND); also elsewhere on the board
unnamed: J1.A5 (CC1), R1.1
unnamed: J1.B5 (CC2), R2.1

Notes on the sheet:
USB-C connector
Power indicator LED
Low dropout (LDO) voltage regulator
The CP2102 module does not require the USB 3.x TX+/TX- and RX+/RX- pins, as it only supports USB 2.0 communication via D+ and D-.
See ESP32 S3 Dev Kit reference design: https://txplo.re/esp32s3ref
The SBU1 and SBU2 pins on a USB-C connector are Sideband Use (SBU) pins. They are part of the USB-C standard and serve specialized roles depending on the application, primarily in Alternate Modes (e.g., DisplayPort, Thunderbolt) and certain USB-C accessories. For basic USB 2.0/3.0 operation (like i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
USB-C allows for reversible cable insertion. Both pairs of data pins (DP1/DN1 and DP2/DN2) are electrically identical but physically flipped depending on the cable orientation.

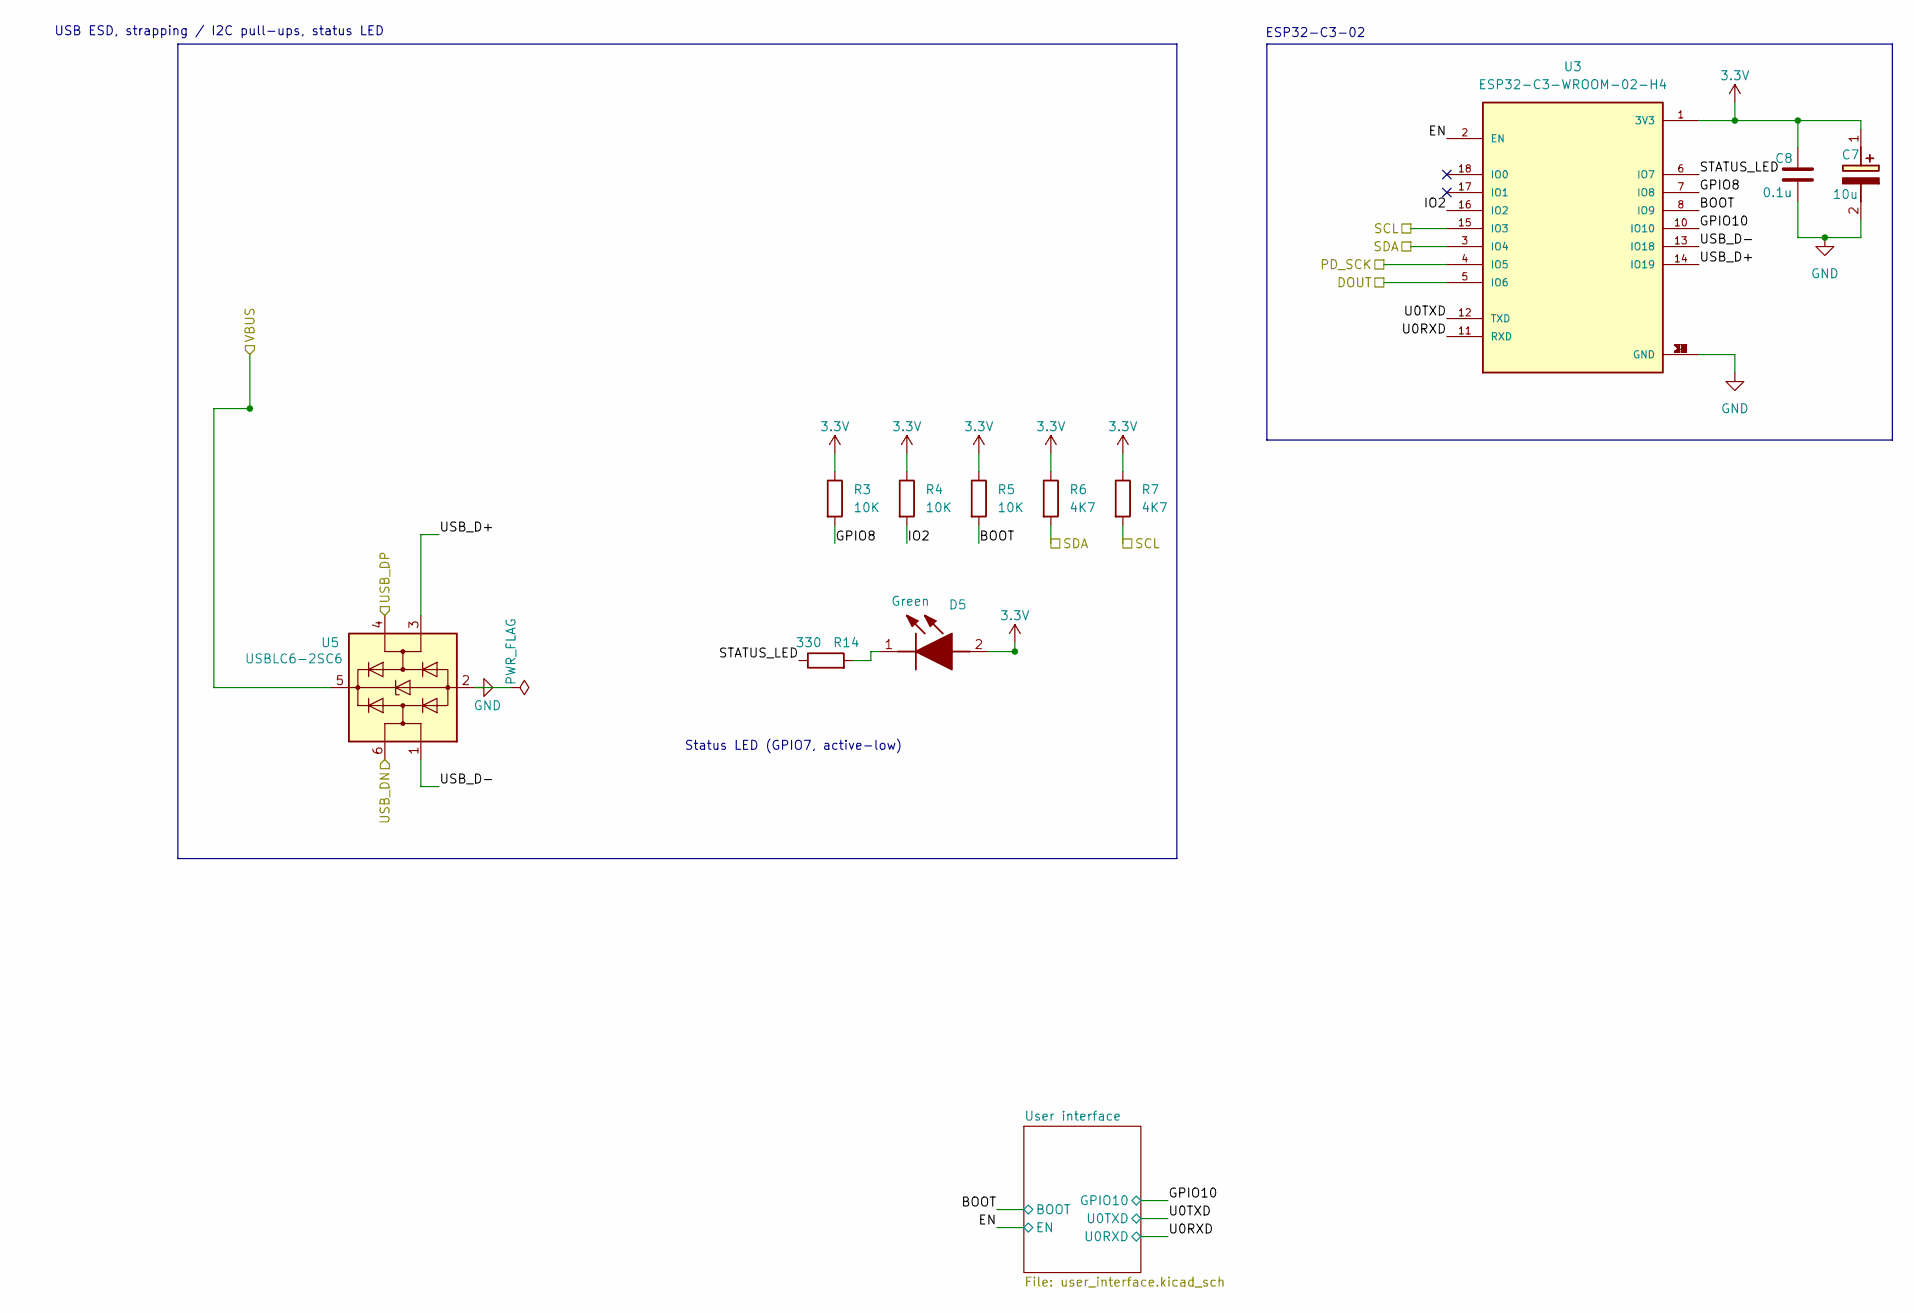
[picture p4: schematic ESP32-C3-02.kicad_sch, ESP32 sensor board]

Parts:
C7: 10u; T491A; Voltage 1kV; Tolerance 100%; Manufacturer_Part_Number T491A106K010AT7280; Mouser Part Number 80-T491A106K107280
C8: 0.1u; C_0805_2012Metric; Voltage 1kV; Tolerance 100%
D5: Green; LEDC2012X120N; Manufacturer_Part_Number LTST-C170GKT; Mouser Part Number 859-LTST-C170GKT
R3, R4, R5: 10K; R_0805_2012Metric
R6, R7: 4K7; R_0805_2012Metric
R14: 330; R_0805_2012Metric
U3: ESP32-C3-WROOM-02-H4; MODULE_ESP32-C3-WROOM-02-H4; Manufacturer_Part_Number ESP32-C3-WROOM-02-H4
U5: USBLC6-2SC6; SOT-23-6; Manufacturer_Part_Number USBLC6-2SC6; Mouser Part Number 511-USBLC6-2SC6

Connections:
3.3V: C7.1 (+), C8.1, D5.2 (A), R3.1, R4.1, R5.1, R6.1, R7.1, U3.1 (3V3); also elsewhere on the board
/ESP32-C3-02/BOOT: R5.2, U3.8 (IO9); also elsewhere on the board
/ESP32-C3-02/DOUT: U3.5 (IO6); also elsewhere on the board
/ESP32-C3-02/EN: U3.2 (EN); also elsewhere on the board
/ESP32-C3-02/GPIO8: R3.2, U3.7 (IO8)
/ESP32-C3-02/GPIO10: U3.10 (IO10); also elsewhere on the board
/ESP32-C3-02/IO2: R4.2, U3.16 (IO2)
/ESP32-C3-02/PD_SCK: U3.4 (IO5); also elsewhere on the board
/ESP32-C3-02/SCL: R7.2, U3.15 (IO3); also elsewhere on the board
/ESP32-C3-02/SDA: R6.2, U3.3 (IO4); also elsewhere on the board
/ESP32-C3-02/STATUS_LED: R14.1, U3.6 (IO7)
/ESP32-C3-02/U0RXD: U3.11 (RXD); also elsewhere on the board
/ESP32-C3-02/U0TXD: U3.12 (TXD); also elsewhere on the board
/ESP32-C3-02/USB_D+: U3.14 (IO19), U5.3 (I/O2)
/ESP32-C3-02/USB_D-: U3.13 (IO18), U5.1 (I/O1)
/USB_DN: U5.6 (I/O1); also elsewhere on the board
/USB_DP: U5.4 (I/O2); also elsewhere on the board
/VBUS: U5.5 (VBUS); also elsewhere on the board
GND: C7.2 (-), C8.2, U3.9 (GND), U3.19 (GND), U3.20 (GND), U3.21 (GND), U3.22 (GND), U3.23 (GND), U3.24 (GND), U3.25 (GND), U3.26 (GND), U3.27 (GND), U3.28 (GND), U3.29 (GND), U3.30 (GND), U3.31 (GND), U3.32 (GND), U3.33 (GND), U3.34 (GND), U3.35 (GND), U3.36 (GND), U3.37 (GND), U3.38 (GND), U3.39 (GND), U5.2 (GND); also elsewhere on the board
unnamed: D5.1 (K), R14.2

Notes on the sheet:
Status LED (GPIO7, active-low)
USB ESD, strapping / I2C pull-ups, status LED
ESP32-C3-02

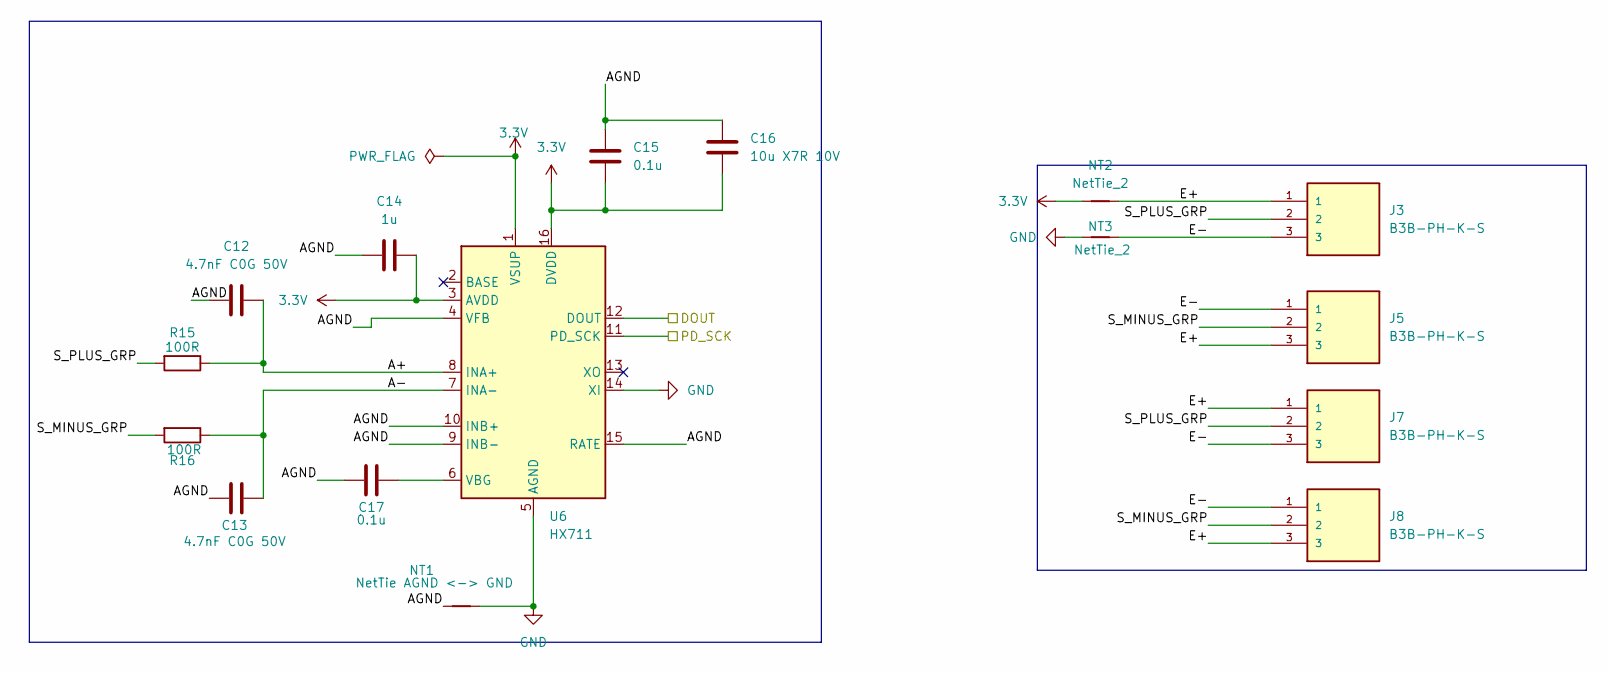
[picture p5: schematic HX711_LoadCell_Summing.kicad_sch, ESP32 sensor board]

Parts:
C12, C13: 4.7nF C0G 50V; C_0805_2012Metric
C14: 1u; C_0805_2012Metric
C15, C17: 0.1u; C_0805_2012Metric
C16: 10u X7R 10V; C_0805_2012Metric
J3, J5, J7, J8: B3B-PH-K-S; JST_PH_B3B-PH-K_1x03_P2.00mm_Vertical
NT1: NetTie AGND <-> GND; NetTie-2_SMD_Pad2.0mm
NT2, NT3: NetTie_2; NetTie-2_SMD_Pad2.0mm
R15, R16: 100R; R_0805_2012Metric
U6: HX711; SOIC-16_3.9x9.9mm_P1.27mm

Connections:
3.3V: C14.2, C15.2, C16.2, NT2.1, U6.1 (VSUP), U6.3 (AVDD), U6.16 (DVDD); also elsewhere on the board
/ESP32-C3-02/DOUT: U6.12 (DOUT); also elsewhere on the board
/ESP32-C3-02/PD_SCK: U6.11 (PD_SCK); also elsewhere on the board
/HX711_LoadCell_Summing/A+: C12.2, R15.1, U6.8 (INA+)
/HX711_LoadCell_Summing/A-: C13.1, R16.1, U6.7 (INA-)
/HX711_LoadCell_Summing/AGND: C12.1, C13.2, C14.1, C15.1, C16.1, C17.2, NT1.1, U6.4 (VFB), U6.9 (INB-), U6.10 (INB+), U6.15 (RATE)
/HX711_LoadCell_Summing/E+: J3.1, J5.3, J7.1, J8.3, NT2.2
/HX711_LoadCell_Summing/E-: J3.3, J5.1, J7.3, J8.1, NT3.2
/HX711_LoadCell_Summing/S_MINUS_GRP: J5.2, J8.2, R16.2
/HX711_LoadCell_Summing/S_PLUS_GRP: J3.2, J7.2, R15.2
GND: NT1.2, NT3.1, U6.5 (AGND), U6.14 (XI); also elsewhere on the board
unnamed: C17.1, U6.6 (VBG)

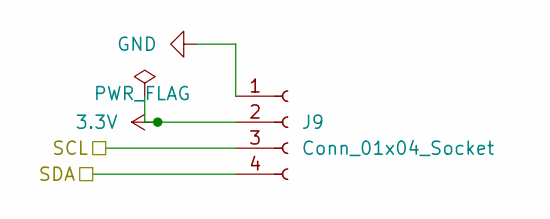
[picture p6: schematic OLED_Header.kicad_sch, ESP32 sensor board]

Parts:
J9: Conn_01x04_Socket; PinSocket_1x04_P2.54mm_Vertical

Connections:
3.3V: J9.2; also elsewhere on the board
/ESP32-C3-02/SCL: J9.3; also elsewhere on the board
/ESP32-C3-02/SDA: J9.4; also elsewhere on the board
GND: J9.1; also elsewhere on the board

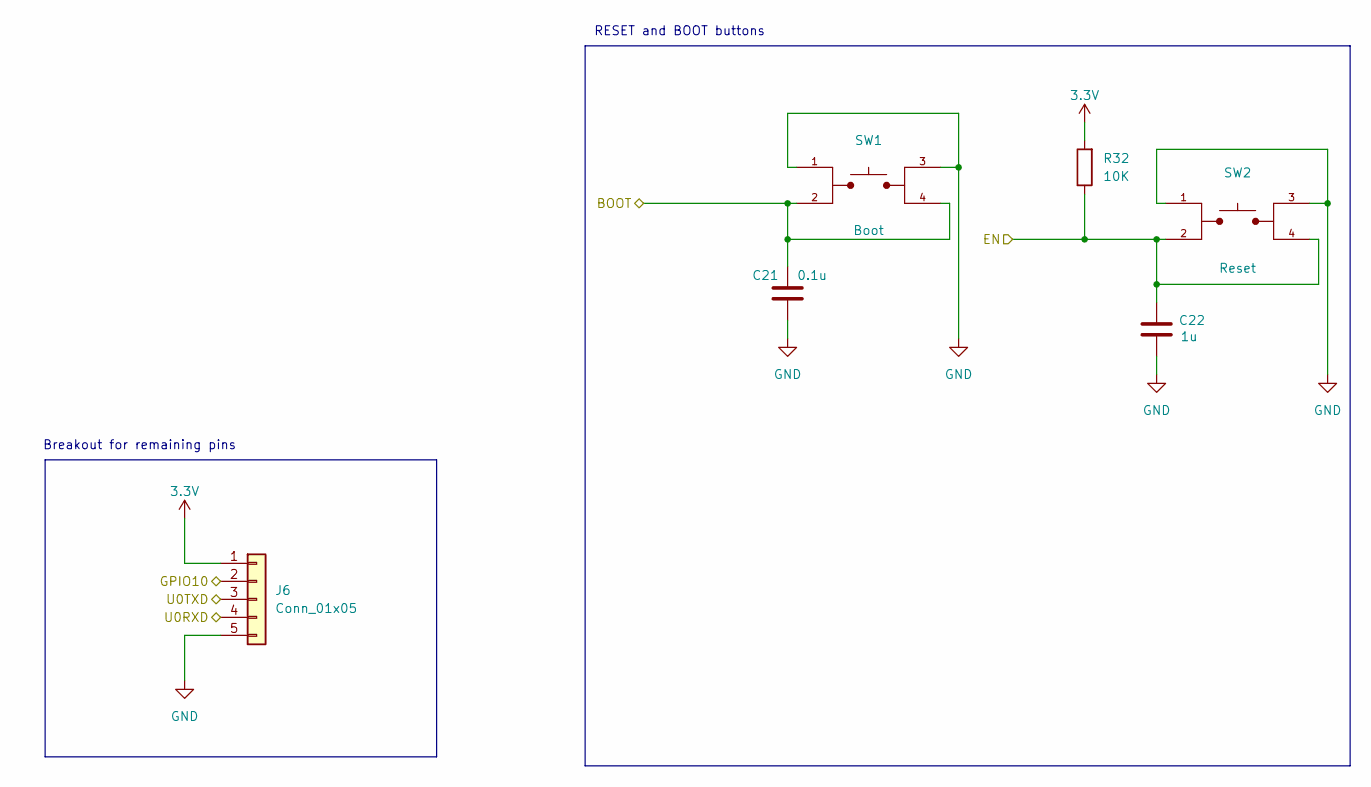
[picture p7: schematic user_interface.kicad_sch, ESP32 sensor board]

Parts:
C21: 0.1u; C_0805_2012Metric; Voltage 1kV; Tolerance 100%
C22: 1u; C_0805_2012Metric; Voltage 1kV; Tolerance 100%
J6: Conn_01x05; PinHeader_1x05_P2.54mm_Vertical
R32: 10K; R_0805_2012Metric
SW1, SW2: 1101NE; SW_TL3305AF260QG; Mfg Part# 8-004 SMD Button 8x3.6mm Height=2.5mm

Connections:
3.3V: J6.1, R32.2; also elsewhere on the board
/ESP32-C3-02/BOOT: C21.1, SW1.2, SW1.4; also elsewhere on the board
/ESP32-C3-02/EN: C22.1, R32.1, SW2.2, SW2.4; also elsewhere on the board
/ESP32-C3-02/GPIO10: J6.2; also elsewhere on the board
/ESP32-C3-02/U0RXD: J6.4; also elsewhere on the board
/ESP32-C3-02/U0TXD: J6.3; also elsewhere on the board
GND: C21.2, C22.2, J6.5, SW1.1, SW1.3, SW2.1, SW2.3; also elsewhere on the board

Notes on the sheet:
RESET and BOOT buttons
Breakout for remaining pins

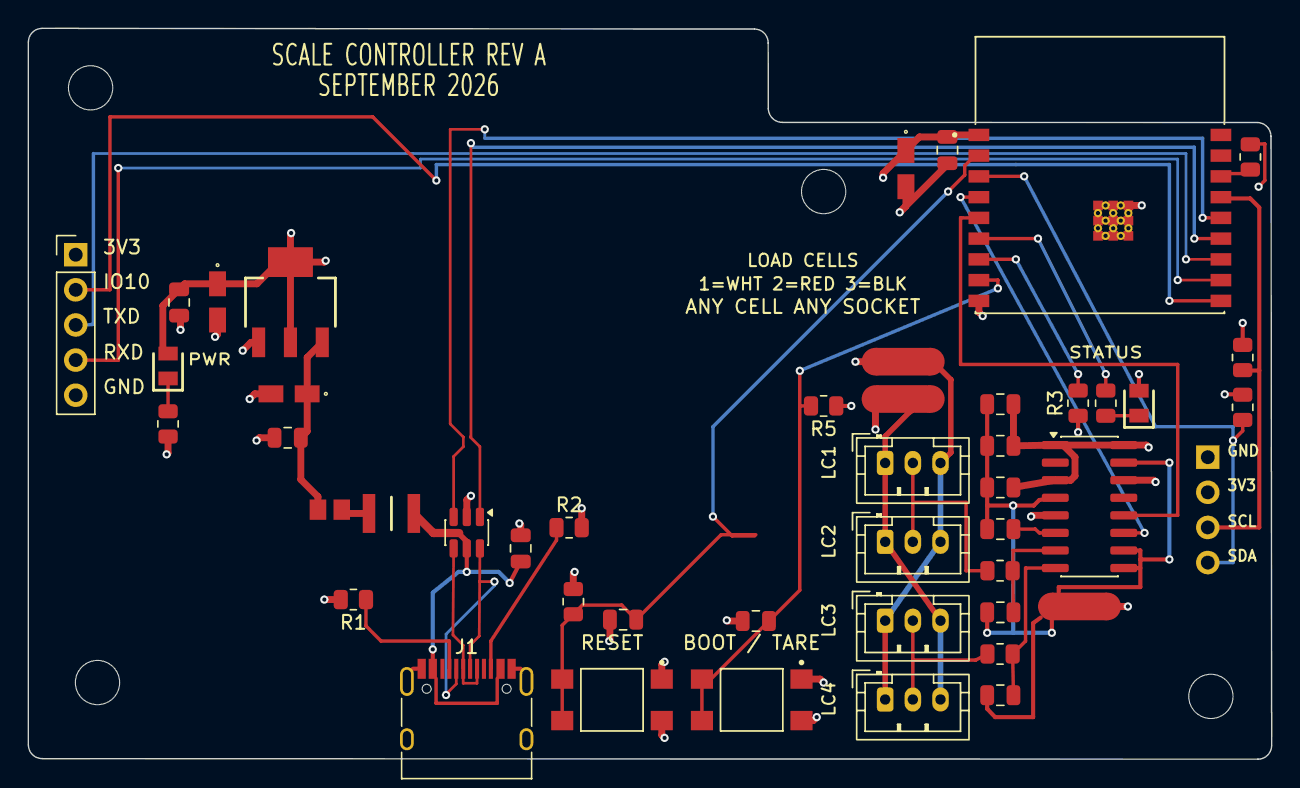
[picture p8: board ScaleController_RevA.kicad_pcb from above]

Board: 4 copper layers, 89.9 x 52.8 mm, 52 parts (1 on the bottom side), 33 nets.

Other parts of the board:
DISP1: OLED 0.96in module (fit check only); OLED_0.96in_I2C_module_under
H1, H2, H3: MountingHole_3.2mm_M3
H4: b; MountingHole_3.2mm_M3

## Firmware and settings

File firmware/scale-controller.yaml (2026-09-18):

# ScaleController Rev-A — ESPHome configuration
#
# Target: ESP32-C3-WROOM-02-H4  (RISC-V, Wi-Fi + BLE)
# Flashing: the ESP32-C3's native USB-Serial/JTAG on the USB-C connector
#   (GPIO18/19). esptool / ESPHome reset the chip and enter download mode over
#   USB automatically. If a board ever refuses, hold BOOT (SW1) while plugging in.
#   Logs also come over this USB port (logger: hardware_uart below).
#
# Verified pin map (from the KiCad netlist, 2026-09-18):
#   HX711 DOUT  -> GPIO6
#   HX711 PD_SCK-> GPIO5
#   I2C  SDA    -> GPIO4    (4.7k pull-up on board, R6)
#   I2C  SCL    -> GPIO3    (4.7k pull-up on board, R7)
#   Tare button -> GPIO9    (reuses the on-board BOOT button SW1; active-low; 10k pull-up R5)
#   Status LED  -> GPIO7    (D5 green, anode to 3.3V via R14 330R: drive LOW to light)
#   USB D-/D+   -> GPIO18/GPIO19 (native USB, do not use as GPIO)
#   Header J6   -> 3.3V, GPIO10, U0TXD (GPIO21), U0RXD (GPIO20), GND
#   Strapping pull-ups on board: GPIO2 (R4), GPIO8 (R3), GPIO9 (R5)
#
# Copy secrets.yaml.example to secrets.yaml and fill in your values before building.

substitutions:
  name: scale-controller
  friendly_name: "Scale Controller"
  # ---- Calibration ----
  # 1. Power on with an empty platform and press Tare (or the HA "Tare" button).
  # 2. Place a known mass (e.g. 1000 g) and read "Scale Raw Counts".
  # 3. calibration_factor = known_mass_g / (raw_counts_with_mass - raw_counts_tared)
  # 4. Put that number below and re-flash.
  calibration_factor: "1.0"

esphome:
  name: ${name}
  friendly_name: ${friendly_name}

esp32:
  board: esp32-c3-devkitm-1
  framework:
    type: esp-idf

logger:
  hardware_uart: USB_SERIAL_JTAG   # native USB CDC; UART0 (J6) stays free for a debug probe

api:
  encryption:
    key: !secret api_encryption_key

ota:
  - platform: esphome
    password: !secret ota_password

wifi:
  ssid: !secret wifi_ssid
  password: !secret wifi_password
  ap:
    ssid: "${friendly_name} Fallback"
    password: !secret ap_password

captive_portal:

# ---- I2C bus (OLED) ----
i2c:
  id: bus_a
  sda: GPIO4
  scl: GPIO3
  scan: true

# ---- Persistent tare offset ----
globals:
  - id: tare_offset
    type: float
    restore_value: yes
    initial_value: "0"

# ---- Sensors ----
sensor:
  - platform: hx711
    id: hx711_raw
    name: "Scale Raw Counts"
    dout_pin: GPIO6
    clk_pin: GPIO5
    gain: 128
    update_interval: 250ms
    internal: true          # raw counts; used for calibration/tare, hidden from HA
    filters:
      - median:
          window_size: 7
          send_every: 4

  - platform: template
    id: weight_g
    name: "Weight"
    unit_of_measurement: "g"
    accuracy_decimals: 1
    update_interval: 250ms
    lambda: |-
      return (id(hx711_raw).state - id(tare_offset)) * ${calibration_factor};
    filters:
      - exponential_moving_average:
          alpha: 0.2
          send_every: 1

# ---- Tare: on-board BOOT button (SW1, GPIO9) + a button entity in Home Assistant ----
# GPIO9 is the BOOT strapping pin. It is only special during power-on/reset;
# at runtime it is a normal input, so SW1 doubles as the tare button.
binary_sensor:
  - platform: gpio
    id: tare_button
    name: "Tare Button"
    pin:
      number: GPIO9
      mode:
        input: true
        pullup: true
      inverted: true         # active-low: SW1 pulls the pin to GND when pressed
    on_press:
      then:
        - script.execute: do_tare

button:
  - platform: template
    name: "Tare"
    on_press:
      then:
        - script.execute: do_tare

script:
  - id: do_tare
    then:
      - lambda: 'id(tare_offset) = id(hx711_raw).state;'

# ---- Status LED: D5 (green) on GPIO7, active-low ----
# ESPHome blinks it while Wi-Fi/API are down and turns it off when everything is up.
status_led:
  pin:
    number: GPIO7
    inverted: true

# ---- OLED display (SSD1306 128x64 @ 0x3C) ----
font:
  - file: "gfonts://Roboto"
    id: font_large
    size: 24
  - file: "gfonts://Roboto"
    id: font_small
    size: 12

display:
  - platform: ssd1306_i2c
    model: "SSD1306 128x64"
    address: 0x3C
    i2c_id: bus_a
    lambda: |-
      it.printf(0, 0, id(font_small), "Weight");
      it.printf(127, 22, id(font_large), TextAlign::TOP_RIGHT, "%.1f g", id(weight_g).state);

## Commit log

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2026-04-12 Add HX711 scale controller schematic and clean up legacy components
    - Add HX711_LoadCell_Summing child sheet with 4x MTMM-103-03-T-S-150 load cell connectors, summing resistors, and decoupling caps
    - Add OLED_Header child sheet (4-pin I2C socket for SSD1306)
    - Remove battery charger (MCP73871), LiPo connector, mic preamp, BME280, SD card from schematic
    - Reconnect power path: +5V_USB -> FB1 -> +5V -> LDO
    - Add Samtec MTMM-103-03-T-S-150 footprint library to fp-lib-table
    - Assign footprints to HX711 passives (C12-C17, R15/R16) and net ties (NT1-NT3)
    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
    [ESP32-C3-02.kicad_sch, HX711_LoadCell_Summing.kicad_sch, OLED_Header.kicad_sch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]
2026-07-05 Clean up repo baseline: remove stale parent-project artifacts
    - Remove old 'ESP32 sensor board' Gerbers, dfm/ output, and stale DRC.rpt
    (all leftovers from the KLP-5e parent project, not this design)
    - Remove orphaned legacy sheet sensors.kicad_sch (not in the active
    hierarchy) and stale ESP32-C3-02.kicad_sch-bak backup
    - Stop tracking regenerable fp-info-cache; add it to .gitignore
    - Ignore ScaleController_RevA-backups/ (KiCad auto-backup folder)
    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
    [ESP32 sensor board-B_Cu.gbl, ESP32 sensor board-B_Mask.gbs, ESP32 sensor board-B_Paste.gbp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]
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2026-07-05 Correct docs + add validated ESPHome config for ESP32-C3
    The README/ESPHome text was inherited from an ESP32-classic template and
    described the wrong MCU and impossible pins. Corrected against the KiCad
    netlist:
    - MCU is ESP32-C3-WROOM-02-H4 (not WROOM-32E); regulator is an LM1117 LDO
    (not a buck); USB is via a CP2102N UART bridge + USBLC6 ESD array.
    - Verified pin map: HX711 DOUT=GPIO6, PD_SCK=GPIO5; I2C SDA=GPIO4, SCL=GPIO3.
    - Tare button (GPIO18) and status LED (GPIO19) documented as planned
    additions (not yet in the schematic).
    Add firmware/scale-controller.yaml (validated with `esphome config`,
    ESPHome 2026.6.4) plus secrets.yaml.example. Gitignore real secrets and
    generated schem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
    [scale-controller.yaml]
2026-07-05 Reuse BOOT button (GPIO9) as tare; no new tare hardware
    Tare now maps to the on-board BOOT button SW1 (GPIO9, active-low) in
    firmware, so no button needs adding to the schematic. Status LED stays
    on GPIO19 (still a planned schematic addition). Re-validated with
    `esphome config` (strapping-pin warning on GPIO9 is expected/benign).
    [scale-controller.yaml]
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2026-07-05 Refresh TODO.md to match current state
    Mark completed items (HX711 sheet, connectors, OLED header, ERC, ESPHome
    config, tare via BOOT, docs). Update pending work to reflect reality: PCB
    routing, DRC, optional status LED, symbol-mismatch cleanup, and bring-up.
    Fix stale pin references (I2C now GPIO4/3, tare via BOOT/GPIO9).
2026-07-05 Defer status LED to Rev-B
    Rev-A ships with no physical status LED (zero schematic risk, fastest path
    to prototype). Status is shown on the OLED and in Home Assistant.
    - Remove the GPIO19 status LED (output/light) from the ESPHome config and
    the tare flash feedback; re-validated with `esphome config`.
    - Update README pin map/features, TODO (moved LED to Rev-B roadmap), and the
    routing plan's open items.
    [scale-controller.yaml]
2026-07-14 Rip up legacy KLP-5e copper; fix board outline
    All 869 track segments and 156 vias dated back to the original KLP-5e
    fork and never matched this design's netlist (128 dangling tracks,
    13 shorts incl. the HX711 DOUT line). Deleted them all; zones are
    kept — GND/power planes and the ESP32-C3 antenna keepout are current.
    Board outline had two defects blocking clean gerbers: a missing
    top-left corner arc and an invisible 2 nm null segment. Added the
    corner arc (1 mm radius, matching the other corners) and removed the
    null segment.
    DRC: 303 -> 128 violations; invalid_outline, track_dangling,
    shorting_items all now zero. Remaining items are mask/silk/lib-sync
    noise. Ratsnest shows the true rou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
    [ScaleController_RevA.kicad_pcb]
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2026-09-14 Record 3.3V power-net split; correct In1.Cu layer-type advice
    Netlist audit before routing found three separate 3.3V nets: "3.3V"
    (SparkFun symbol, root/C3/UI sheets, LDO output), "+3.3V" (power:+3.3V,
    HX711 sheet, 7 pins) and "+3V3" (power:+3V3, OLED header pin 1). No net
    tie joins them, so the HX711 and OLED have no supply. ERC does not flag
    this because each power symbol drives its own net.
    Also fixes the routing plan: KiCad has no "ground" layer type, so
    In1.Cu correctly stays as a power-plane layer.
2026-09-14 Unify 3.3V power nets; update PCB netlist
    The HX711 sheet used power:+3.3V (4 symbols) and the OLED header sheet
    used power:+3V3, which are separate nets from the SparkFun 3.3V symbol
    used on the root, ESP32-C3 and UI sheets. The HX711 (VSUP/AVDD/DVDD,
    decoupling, E+ net tie) and the OLED VCC pin were therefore unpowered.
    Changed the five symbols' Value to 3.3V so they join the LDO rail:
    one 3.3V net with 25 pins. ERC: 0 errors (87 library warnings, as before).
    Updated PCB from schematic: +3.3V/+3V3 nets gone, 66 nets, 138 unrouted
    connections (was 136). KiCad also normalized symbol-instance project
    names in all sheets from the old KLP-5e parent names.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
    [ESP32-C3-02.kicad_sch, HX711_LoadCell_Summing.kicad_sch, OLED_Header.kicad_sch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]
2026-09-14 Remove stale F.Cu micro-pours and duplicate In1.Cu GND zones
    Deleted the eight small top-layer copper zones inherited from the KLP-5e
    layout (three were isolated copper, one had no net) and two of the three
    overlapping GND zones on In1.Cu. Remaining copper zones: GND plane on
    In1.Cu; 3.3V, VBUS and +5V_USB on In2.Cu; plus the antenna rule area.
    DRC: 140 unrouted (was 138 — two pad pairs were previously bridged by the
    deleted pours and now show as ratsnest), 123 violations (was 128; the
    items-in-keepout and three isolated-copper items cleared). Remaining
    non-cosmetic items are all on the USB-C connector J1: eight pad-to-pad
    clearances inherent to the hybrid footprint (0.15 mm gaps vs 0.2 m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
    [ScaleController_RevA.kicad_pcb]
2026-09-14 Add J1 pad-spacing rule; solid plane connection for J1
    The BELFUSE_SS-52400-002 USB-C hybrid footprint has 0.65 mm PTH pads on
    a staggered 0.8 mm pitch (0.15 mm gaps), below the 0.2 mm GND netclass
    clearance. A custom rule scoped with memberOfFootprint('J1') allows
    0.127 mm between J1's own pads. (A.Reference == 'J1' does not match pads.)
    J1's footprint now uses solid zone connection so its PTH GND pins tie
    straight into the In1.Cu plane; thermal spokes could not fit between
    the closely spaced pads.
    DRC: 0 errors beyond mask/silk/lib noise; 1 isolated-copper warning
    (+5V_USB island on In2.Cu, to be removed during power routing).
    [ScaleController_RevA.kicad_pcb]
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2026-09-14 Pre-routing prep: purge legacy silk, add mounting holes, fix net classes
    - Removed all 104 board-level F.SilkS graphics/text inherited from the
    KLP-5e board (Charger, Sound sensor, SPI labels, old J6 pinout, ...).
    - Added four M3 mounting holes H1-H4 (board-only, excluded from BOM/POS,
    reference text hidden) at (116,76.5) (116.5,119.5) (197,120.5) (169,84).
    - Moved FB1 from the bottom edge to beside F1 at (133.3,107) rot 0 so the
    VBUS -> F1 -> FB1 -> U2 chain is straight.
    - Net classes: Default and 5V_USB vias 0.3/0.3 -> 0.5/0.3; 5V_USB track
    0.25 -> 0.5 mm; "+5V" assigned to 5V_USB.
    - Deleted the In2.Cu VBUS and +5V_USB islands; In2 is now a solid 3.3V
    plane. Those nets route on F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
    [ScaleController_RevA.kicad_pcb]
2026-09-15 Route power chain: VBUS, +5V_USB, +5V, local 3.3V; two 3.3V vias to In2
    First routing chunk, all F.Cu: J1 VBUS pads (0.3 mm stubs) -> U5 -> F1
    and C1 -> R12; F1 -> FB1; FB1 -> C2 -> C3 -> U2 in; U2 out -> tab ->
    C4 -> C5 -> D4, with two 0.6/0.4 vias from the tab onto the In2.Cu 3.3V
    plane. J6 pin 1 now reaches 3.3V through the plane.
    DRC: 126 unrouted (was 141), 86 violations, all cosmetic. One +5V
    track has a small gap to close.
    [ScaleController_RevA.kicad_pcb]
2026-09-15 Route 3.3V distribution: F.Cu links per cluster, vias to In2 plane
    Closed the +5V gap (C2 -> C3). Routed 3.3V clusters on F.Cu with a via
    to the In2.Cu plane at each: CP2102N (U4 pads 6/7 -> C10 -> C9, R11,
    R32, D5/D6), ESP32-C3 (U3 pin 1 -> C8 -> C7), HX711 (U6 pins 1/3/16,
    C14-C16, NT2). J1 footprint now allows bridged solder-mask apertures
    (0.5 mm pitch), clearing 53 mask-bridge errors.
    DRC: 107 unrouted (was 126). Two vias at (192.5,102.5) and (184.5,118)
    are 0.4/0.2 and must be resized to 0.6/0.4.
    [ScaleController_RevA.kicad_pcb]
2026-09-15 Route GND: via to In1 plane at every SMD ground pad
    41 GND connections closed: stub-and-via at each SMD GND pad (25 vias,
    0.6/0.4), J1 A1/A12 tied to the PTH shell pins below them, G3/G4 tied to
    the S1-S4 shell legs, U4 GND pins into its exposed pad, ESP32-C3 module
    ground grid linked by short tracks. Resized the two 0.4/0.2 3.3V vias
    to 0.6/0.4.
    DRC: 66 unrouted (was 107), 34 violations, all lib-sync/module-outline.
    [ScaleController_RevA.kicad_pcb]
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2026-09-15 Fix HX711 input filter topology; remove stale test points
    C12/C13 were in series with the load-cell signal (S -> 100R -> 4.7nF ->
    INA), which blocks the DC bridge output. R15/R16 now feed INA+/INA-
    directly and C12/C13 shunt those nodes to AGND. Removed TP2 (DOUT) and
    TP4 (PD_SCK), leftovers from the KLP-5e board. Netlist: 64 nets, ERC 0
    errors. PCB updated from schematic; 66 unrouted, DRC unchanged.
    [ESP32-C3-02.kicad_sch, HX711_LoadCell_Summing.kicad_sch, ScaleController_RevA.kicad_pcb]
2026-09-15 Route HX711 analog section; re-place filter parts and net ties
    Placement: J5/J7 swapped so S+ connectors (J3, J7) and S- connectors
    (J5, J8) are adjacent; cap/resistor column re-ordered pin-by-pin
    (C16, C15, C14 supply caps at top; C17 by VBG; R16/C13 by INA-;
    R15/C12 by INA+); NT2 moved beside the connectors with its own 3.3V
    via; NT3 moved to the bottom edge by the connectors with its own GND via.
    Routing (F.Cu unless noted): E+ chain through connector pin 1; E- chain
    on B.Cu through pin 3; S+/S- to the 100R filters; INA+/INA- from the
    filter nodes with shunt caps to AGND; VBG bypass; AGND network (left
    column, U6 pins 4/9/10/15) meeting GND only at NT1; DOUT on F.Cu and
    PD_SCK on B.Cu to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
    [ScaleController_RevA.kicad_pcb]
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2026-09-15 Route remaining digital nets; board fully routed (0 unrouted)
    Steve (GUI): USB D+/D- from J1 to U5 to U4 with bottom-layer hops,
    CP2102N support parts (RST, VBUS sense divider, LED resistors), power
    LED, reset/boot button cluster with Q2/Q3, RTS/DTS to the auto-program
    circuit, EN and BOOT to the module, SCL down the right edge to J9.
    Headless batch: J1 B7 to D- (B.Cu loop around the pin rows); SDA
    under the module on B.Cu to J9; a five-lane B.Cu bus along the top edge
    (TX_RX, RX_TX, GPIO18, GPIO19, GPIO8) from the module to U4 and J6, with
    GPIO8/GPIO19 hopping to F.Cu for the J6 approach. BOOT's F.Cu loop over
    module pins 5-7 replaced by a B.Cu diagonal ending inside the module
    (it boxed i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
    [ScaleController_RevA.kicad_pcb]
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2026-09-17 Load-cell connectors: JST PH friction-lock, cells 3/4 inverted on-board
    Schematic: J3/J5/J7/J8 footprints changed to JST_PH_B3B-PH-K_1x03 (top
    entry, 2.0 mm, friction lock) replacing the plain Samtec MTMM pin
    headers that would let plugs walk off. Connector symbol pins renumbered
    01/02/03 -> 1/2/3 to match the JST pad numbering. One connector pair
    (J3/J7 vs J5/J8) now has E+/E- swapped so all four half-bridge cells plug
    in identically and the PCB provides the required inversion; the user no
    longer swaps white/black on two cells. Note: as wired, the net named E+
    ties to GND (NT3) and E- to 3.3V (NT2); functionally correct, naming to
    tidy later.
    Board: JST pads netted; rows spread to 5.7 mm p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
    [HX711_LoadCell_Summing.kicad_sch, ScaleController_RevA.kicad_pcb]
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2026-09-17 Refill zones after connector rework
    DRC: 0 unrouted, 4 warnings (J1/U3 intentional lib mismatch, 2 module outline vs edge).
    [ScaleController_RevA.kicad_pcb]
2026-09-17 Swap E+/E- labels so E+ is the 3.3V-side excitation again
    Pure rename: the four E+ and four E- labels on the HX711 sheet exchanged,
    and the two net names on the board exchanged to match. No wire, pad or
    track changed. Netlist: E+ = J3.1 J5.3 J7.1 J8.3 NT2.2 (3.3V tie);
    E- = J3.3 J5.1 J7.3 J8.1 NT3.2 (GND tie). ERC 0 errors; DRC 0 unrouted,
    4 warnings; every pad net on the board matches the schematic.
    [HX711_LoadCell_Summing.kicad_sch, ScaleController_RevA.kicad_pcb]
2026-09-17 Silkscreen labels
    Load-cell sockets LC1-LC4 with wiring legend (1=WHT 2=RED 3=BLK, any
    cell to any socket), RESET and BOOT/TARE buttons, J6 and J9 pin names,
    PWR/TX/RX LEDs, board name and date. 23 board-level texts, F.SilkS,
    0.75-1.5 mm height, 0.15 mm stroke. Connector reference designators
    hidden in favour of the LC labels.
    DRC: 0 unrouted, 4 warnings (J1/U3 lib mismatch, U3 outline over the
    antenna notch).
    [ScaleController_RevA.kicad_pcb]
2026-09-17 USB-C: HRO TYPE-C-31-M-12 receptacle, CC pull-downs, VBUS/GND short removed
    J1 replaced by Connector:USB_C_Receptacle_USB2.0_16P with the
    Connector_USB HRO TYPE-C-31-M-12 footprint (SMD signal pins, 4 PTH
    shell legs) in place of the Bel SS-52400-002, whose staggered PTH row
    (0.35 mm hole spacing, 0.10 mm rings) fell below PCBWay's normal process.
    Added R1/R2 5.1k CC1/CC2 pull-downs so the board powers from USB-C
    chargers and C-to-C cables. Removed a leftover wire that bridged C1 and
    shorted VBUS to GND after the edit. 57 nets, ERC 0 errors.
    [ScaleController_RevA.kicad_sch]
2026-09-17 DFM pass for PCBWay: USB-C rework, 0.15 mm via rings, pad and rule fixes
    USB corner rebuilt around the HRO TYPE-C-31-M-12: J1 placed with the
    pad row 6.4 mm from the board edge per datasheet; D+/D- from the A pins
    straight to the ESD array with the B6 join as an inner loop and the B7
    join hopping the bottom layer; VBUS pins joined by an inner loop and
    brought out through vias to U5, F1, C1 and R12; CC1/CC2 to R1/R2 (5.1k)
    with GND vias; GND pins tied to the shell legs. Pad nets re-synced from
    the schematic (14 corrected after the earlier shorted update).
    DFM: all vias now 0.6/0.3 (0.15 mm ring; one 0.55/0.3 at U4 pad 8 where
    the RST/C10 gap allows no more); ESP32 module ground-grid PTH pads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
    [ScaleController_RevA.kicad_pcb]
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2026-09-17 OLED header J9 on the back side with the module's pin order
    J9 rewired to 1=GND 2=3V3 3=SCL 4=SDA (the order on the 0.96in Hosyond
    I2C module) and flipped to the bottom side, so the module plugs in from
    below and lies flat under the board, clear of the load-cell sockets.
    SCL/SDA tails re-routed to the swapped pads; 3V3/GND land on the planes.
    J9 labels reordered on top and duplicated mirrored on the back. The
    DISP1 placeholder now models the 0.96in module (27 x 27.5 mm) under the
    board, replacing the 1.3in upright placeholder.
    Fills stale in this commit (refill in GUI). Enclosure note: standoffs
    under the board need >= 14 mm for the module.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
    [OLED_Header.kicad_sch, ScaleController_RevA.kicad_pcb, ScaleController_RevA.kicad_sch]
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2026-09-18 Pre-order tidy: DRU, symbol-lib sync, PCBWay stackup, JST part number on J3/5/7/8
    - .kicad_dru: drop the global annular_width ignore. U3's ground-grid pads
    are 0.6/0.3 mm since the DFM pass; DRC is identical without the rule.
    - Project symbol libs for LM1117MPX-3.3_NOPB, ESP32-C3-WROOM-02-H4 and
    MTMM-103-03-T-S-150 rewritten in KiCad 9 format from the schematic
    copies (the MTMM copy has pins 1/2/3 to match the JST PH pads; the old
    lib still had 01/02/03). SnapEDA "Description_1" junk fields removed
    from libs, embedded copies and instances. ERC: 0 lib_symbol_mismatch.
    - Stackup: PCBWay standard 4-layer 1.6 mm (7628 prepreg 0.19 x2,
    core 1.03, 1 oz all layers).
    - J3/J5/J7/J8: Value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
    [ESP32-C3-02.kicad_sch, HX711_LoadCell_Summing.kicad_sch, ScaleController_RevA.kicad_pcb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]
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2026-09-18 BOM fixes, DRC exclusions, edge-clearance restore, fab outputs and order notes
    - C9 value 4.7u -> 10u (matches its KEMET T491A 10 uF part number; LM1117
    output cap). Capacitor values normalised to 0.1u / 1u / 10u so identical
    0805 parts group: BOM 30 -> 27 lines.
    - J1 value -> HRO TYPE-C-31-M-12, MF/MP fields added (schematic + board).
    - min_copper_edge_clearance restored to 0.3 mm. The DFM commit 4617449 set
    it; the GUI refill save in 61ca090 wrote the old project file back (0.2).
    Board meets 0.3 (probe rule: no violations).
    - DRC exclusions for the 4 silk-over-edge warnings (J1 face, U3 antenna
    notch), added in the GUI.
    - docs/pcbway-order-notes.md: board spec, stackup, drills, s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
    [ESP32-C3-02.kicad_sch, HX711_LoadCell_Summing.kicad_sch, ScaleController_RevA.kicad_pcb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]
2026-09-18 Specify dielectric and source for the HX711 front-end parts in the BOM
    - C12/C13: Value "4.7nF C0G 50V", description marks them as the matched
    HX711 input-filter pair, no Class 2 substitution.
    - C16: Value "10u X7R 10V", description forbids Y5V.
    - U6: MF/MP Avia Semiconductor HX711 added; description notes it is
    noise-critical and must be genuine or a known-good source.
    - Order notes and status note updated accordingly.
    Value fields are on F.Fab only; Gerbers unchanged. Netlist nets/pins
    identical. DRC + parity: 0 errors, 0 parity issues.
    [HX711_LoadCell_Summing.kicad_sch, ScaleController_RevA.kicad_pcb]
2026-09-18 Netlist-level schematic review against datasheets
    Two design errors in the programming path (CP2102N QFN20 has no DTR, so
    the DTR/RTS auto-program circuit is driven from CTS; GPIO8 floats but must
    be high for download boot), plus robustness notes. Workarounds for Rev-A
    need no board change: DNP Q2/Q3/R33/R34, 10k across J6 pins 1-2.
2026-09-18 Schematic: native USB-Serial/JTAG replaces the CP2102N; strapping and I2C pull-ups; status LED
    Review findings F1-F5 (docs/schematic-review-2026-09-18.md), Level 1 + 2:
    - Removed U4 CP2102N and its support parts (R11, R12, R13, C9, C10, C11,
    D6, R18) and the DTR/RTS auto-program circuit (Q2, Q3, R33, R34).
    The QFN20 CP2102N has no DTR, so that circuit could never work.
    - USB D+/D- now run from the ESD diode U5 to the module's native USB pins
    (IO19 = USB_D+, IO18 = USB_D-). Reset and download-mode entry are handled
    by the USB-Serial/JTAG peripheral.
    - Pull-ups: R3 10k GPIO8 (required high for download boot), R4 10k GPIO2
    (recommended), R5 10k GPIO9/BOOT, R6/R7 4.7k SDA/SCL.
    - D5 (gr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
    [ESP32-C3-02.kicad_sch, scale-controller.yaml, user_interface.kicad_sch]
2026-09-18 Schematic: refresh sheet captions after the USB rework; drop the stale auto-program table
    [ESP32-C3-02.kicad_sch, user_interface.kicad_sch]
2026-09-18 Fix: restore J6 ground symbol removed by mistake with the stale auto-program note
    [user_interface.kicad_sch]
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2026-09-18 Board: zones refilled (GUI); remove the last dead copper from the CP2102N/Q3 removal; docs updated
    - Removed 4 orphan plane vias, the dead BOOT branch that fed Q3 (2 vias,
    4 segments) and the VBUS stub that fed the removed sense divider.
    - DRC on the refilled board: 0 errors, 0 unconnected, 0 parity issues;
    remaining warnings are the 4 excluded silk items and the intentional
    U3 library note.
    - Order notes: 44 parts / 23 BOM lines, no 0.55 mm via, no via-in-pad,
    native USB note. Status note: rework section, regenerated package.
    TODO: review findings F1-F5 closed in Rev-A.
    [ScaleController_RevA.kicad_pcb]
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2026-09-18 Schematic: title blocks (Scale Controller, rev A, 2026-09-18, per-sheet comments); replace stale CP2102 and ESP32-S3 notes
    [ESP32-C3-02.kicad_sch, HX711_LoadCell_Summing.kicad_sch, OLED_Header.kicad_sch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]
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2026-10-01 Mechanical: puck cable-end and overload-stop mod C, Fusion parameters, build script
    Splice pocket, cable groove, M2 clamp bar with heat-set inserts, and six fixed stop
    pads on Puck_Bottom; cutter bodies for overlaying in Fusion; CableMod_Parameters.csv
    in Fusion's parameter format; README records cable choice, pin/colour mapping and
    the accepted sub-2.5 mm walls around the clamp inserts.
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2026-10-01 Mechanical: test-print-1 fixes (measured cell dome 7.56, M2 post inserts) and ParameterIO update file
2026-10-04 Mechanical: clamp ridges 7 -> 4.2 mm so they fit the 4.6 mm groove
    The 7 mm ridges landed on the recess floor either side of the groove and held the
    bar ~1 mm high (4.8 mm3 bar/bottom interference in the Fusion model). With 4.2 mm
    ridges the interference is zero and the bar seats for a 0.6 mm squeeze on the
    measured 4.2 mm cable. ParameterIO update file included.
2026-11-01 Bring-up: Rev-A smoke test on board #1, SW1/SW2 short found
    - docs/bringup-2026-11-01.md: results (USB, boot, Wi-Fi, LED, I2C, HX711 with
    LC1 + LC4) and finding B1: the TL3305 buttons are wired across their
    internally joined pins, shorting EN and GPIO9 to GND. Workaround: remove
    SW1/SW2 or cut one diagonal pair of legs. Rev-B fix noted in TODO.
    - firmware/smoke-test.yaml: no-Wi-Fi bring-up firmware (LED blink, I2C scan,
    HX711 raw/delta over USB logs).
    - scale-controller.yaml: raw counts visible in HA for calibration; note that
    the BOOT tare is unavailable on Rev-A.
    - README: native USB (no CP2102N), J6 pins, status LED, socket pairs, Rev-A
    button warning. Schematic review: S+ pai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
2026-11-08 Bench test: Wi-Fi smoke-test firmware, all four cells confirmed
    - smoke-test.yaml: Wi-Fi, HA API, OTA, web page, Zero/Restart buttons and
    Wi-Fi signal, so the board can be read remotely on the bench.
    - Bring-up note: all four sockets respond the same direction in a puck
    (~-220k counts per press); flat-on-bench cells barely register; 21 h on
    Wi-Fi with no dropouts and +/-50 count noise; ~10k count baseline wander.
    - TODO: ticked socket and Wi-Fi checks.
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2026-11-08 Firmware v0.1.0: scale component and packages per the spec
    - components/scale: weighing logic (Zero/Calibrate wait for a stable
    reading, stable weight, weigh-in state machine and event, reporting on
    change + heartbeat or fixed interval, optional auto-zero, faults with a
    Status reason, status LED modes). Entities are declared in YAML and
    handed to the component.
    - packages/board-rev-a.yaml: Rev-A pins, LED output, USB logger.
    - packages/scale-core.yaml: HA entities, settings (restored across
    reboots), diagnostics, web_server v3.
    - scale-controller.yaml: now just device, network and the two packages.
    Flashed OTA to board #1: boots, reads the cells, reports "Not
    calibrated" as design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
2026-11-08 Firmware: scale-specific web page served from the device
    - web/scale-ui.js (~8 KB gzipped): replaces ESPHome's entity list.
    Scale view (big live weight, stable/settling, status, Zero, last
    weigh-in), guided calibration wizard driven by the Status text,
    grouped settings with help text and kg/lb conversion, diagnostics,
    restart and a link to the stock ESPHome page. Mobile-first, light and
    dark mode, no internet needed.
    - web_server: js_url "" + js_include, so nothing loads from oi.esphome.io.
    - Scale component: Live weight (4/s) and Stable entities for the page,
    disabled by default in HA.
    - Spec: layout updated (single file, no build step).
    Checked on board #1 with headless Chromi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
